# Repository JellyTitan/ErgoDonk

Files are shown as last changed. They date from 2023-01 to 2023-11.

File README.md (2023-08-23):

# ErgoDonk v0.9
ErgoDox variant that uses standard 100% SA keycaps, Blackpill MCU and an FDM printed case. 
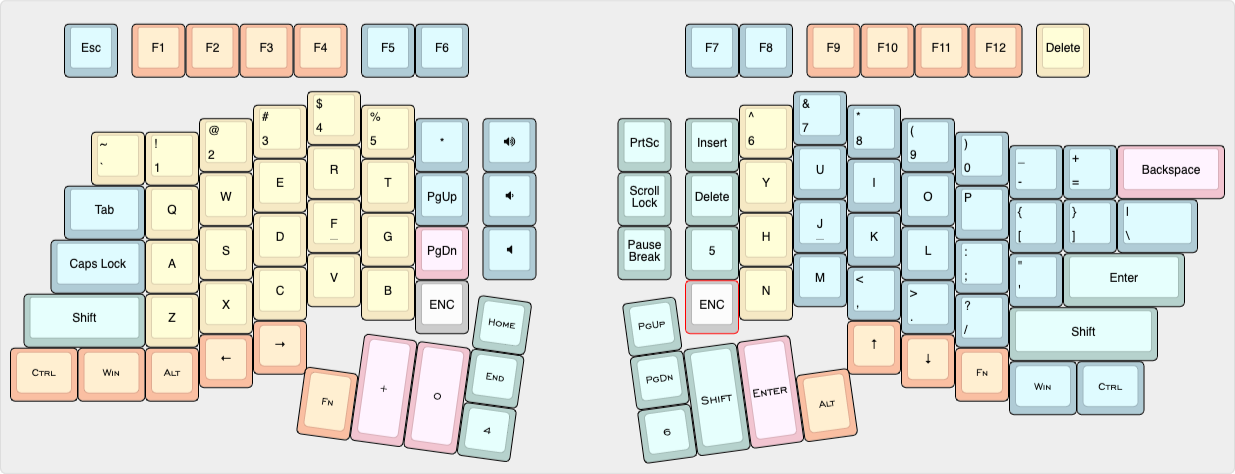
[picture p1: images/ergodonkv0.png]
ErgoDonk key layout

[keyboard layout editor](http://www.keyboard-layout-editor.com/#/gists/ac776db3b0deef94de51943c384cfdfc)

## Build Log
Experiments to date:
* Prototype initially built with Blackpill MCU. Works well.
* Refactored to use LED
* Refactored to use ProMicro
* Refactored to use Pico 2040
* Prototype sent out for production 7-26-2023

### Lessons learned from the ds simple prototype (todo)
* Fix the stabilizers. Two screw-in PCB stabalizers won't fit next to each other on the thumb cluster - try the plate mount stabs instead.
Plate mount stabs mirrored
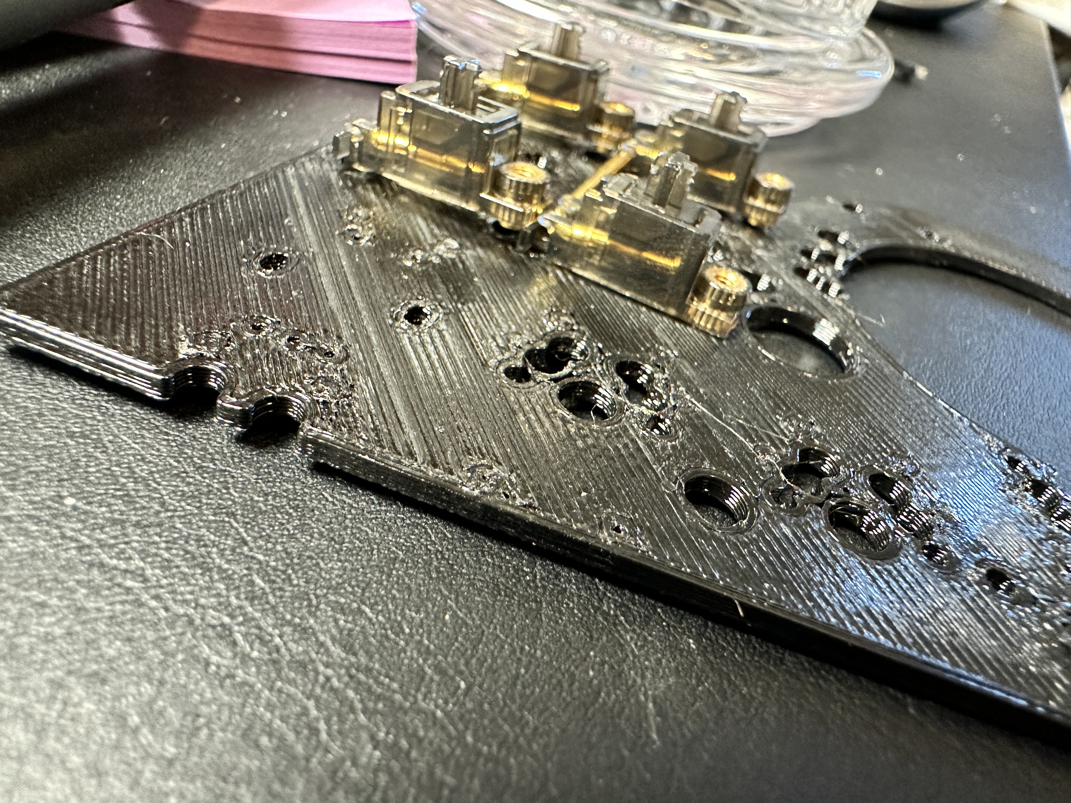
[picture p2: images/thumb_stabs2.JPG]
Plate mount stabs oriented same

* Take a closer look at routing by the rotary encoders - may be a short
* The DS version is charged as two keyboards by JLCPCB - compare pricing for building as two seperate halves.
* The RH Trackball has 2 separate pcbs. Top one sent out for prototype, bottom needs to be made.

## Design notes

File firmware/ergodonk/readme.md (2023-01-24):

# ergodonk_v2

ergodonk_v2

*A short description of the keyboard/project*

* Keyboard Maintainer: [Ryan Neff](https://github.com/JellyTitan)
* Hardware Supported: *The PCBs, controllers supported*
* Hardware Availability: *Links to where you can find this hardware*

Make example for this keyboard (after setting up your build environment):

    make ergodonk_v2:default

Flashing example for this keyboard:

    make ergodonk:default:flash
    For EE_HANDS (Extra steps required on ARM @todo maybe pull this?)
    make ergodonk:default:flash:dfu-util-split-left
    make ergodonk:default:flash:dfu-util-split-right

    qmk compile -kb ergodonk_v2 -km default

    c2json (Must run from inside keymap folder)
    `qmk c2json -kb ergodonk -km default keymap.c`
    
See the [build environment setup](https://docs.qmk.fm/#/getting_started_build_tools) and the [make instructions](https://docs.qmk.fm/#/getting_started_make_guide) for more information. Brand new to QMK? Start with our [Complete Newbs Guide](https://docs.qmk.fm/#/newbs).

## Bootloader

Enter the bootloader in 3 ways:

* **Bootmagic reset**: Hold down the key at (0,0) in the matrix (usually the top left key or Escape) and plug in the keyboard
* **Physical reset button**: Briefly press the button on the back of the PCB - some may have pads you must short instead
* **Keycode in layout**: Press the key mapped to `RESET` if it is available

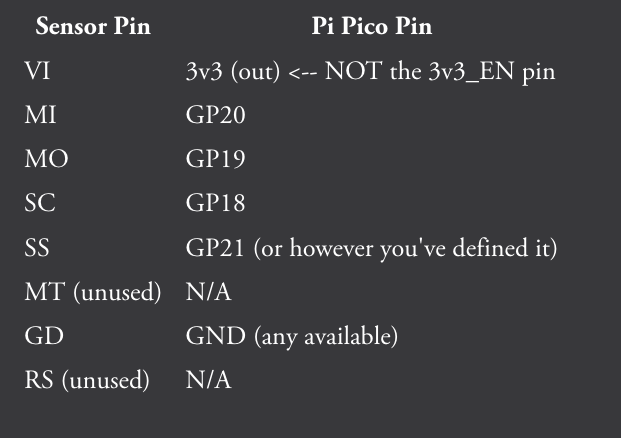
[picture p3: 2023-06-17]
reference_images/pmw3360_pico_pinout.png

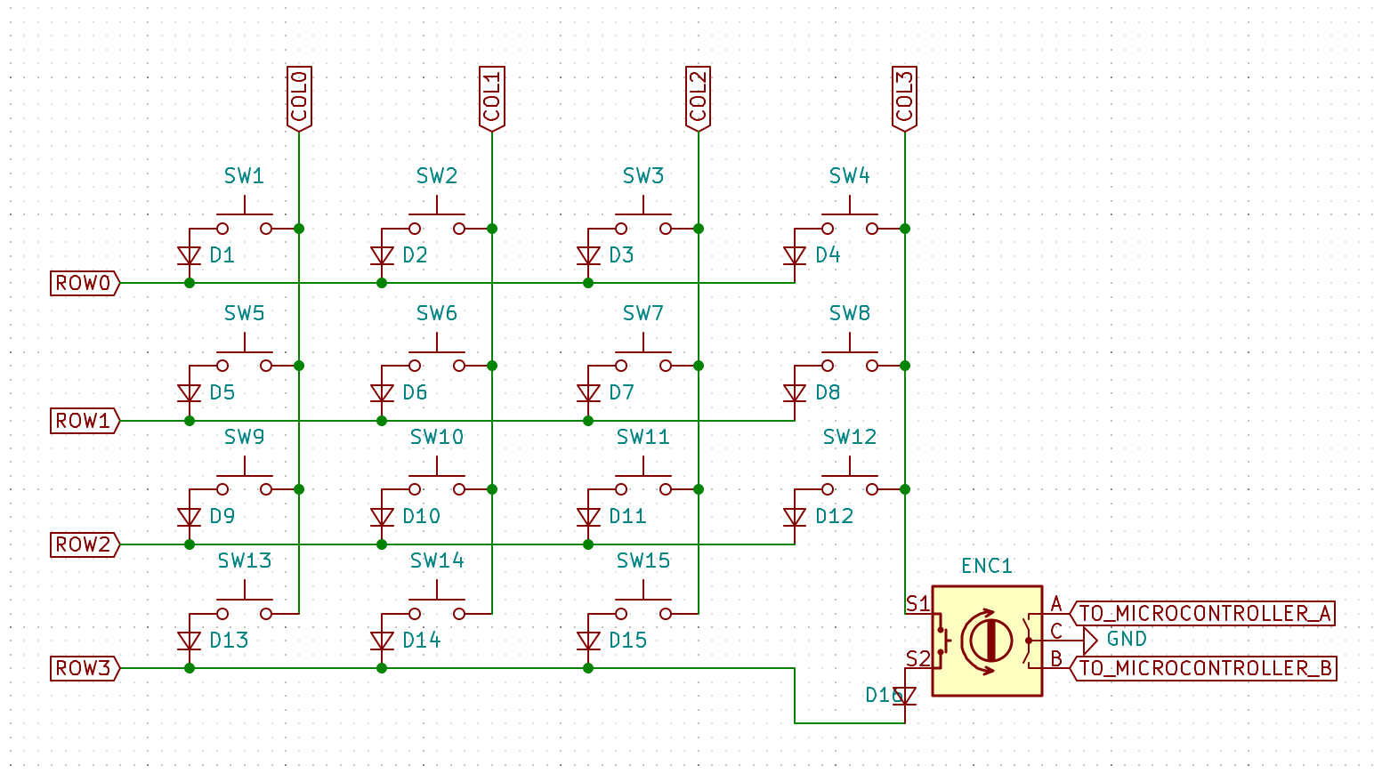
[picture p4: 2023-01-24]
reference_images/rotary_encoder_schematic.png

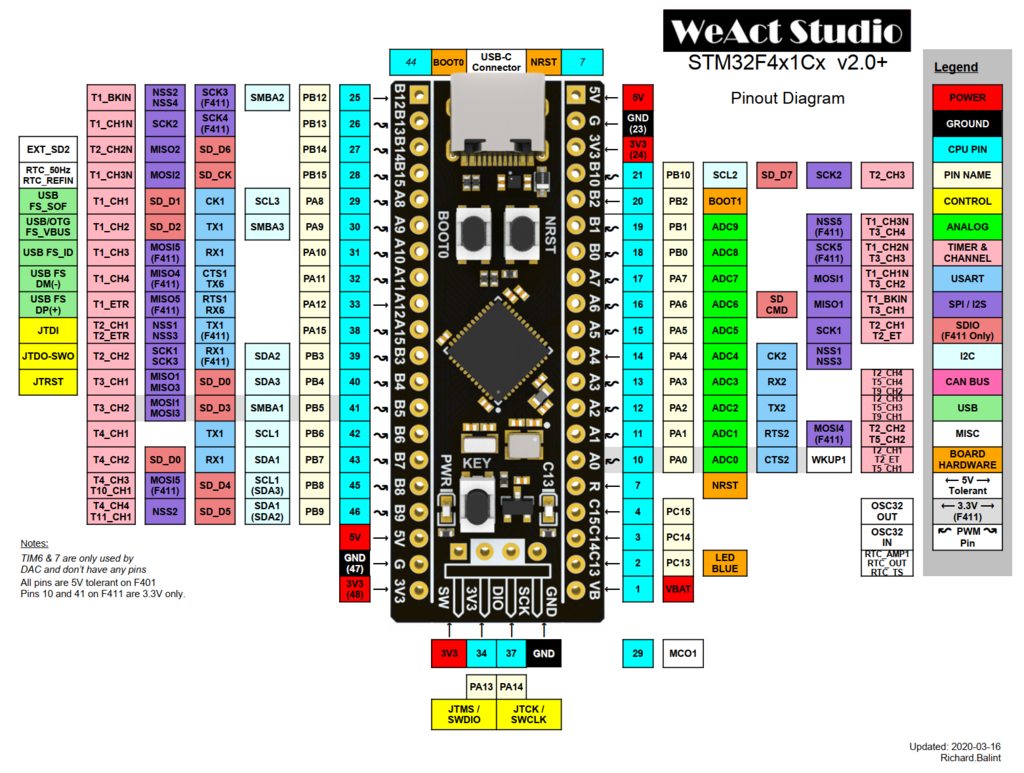
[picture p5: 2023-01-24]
reference_images/blackpill_pinout.jpeg

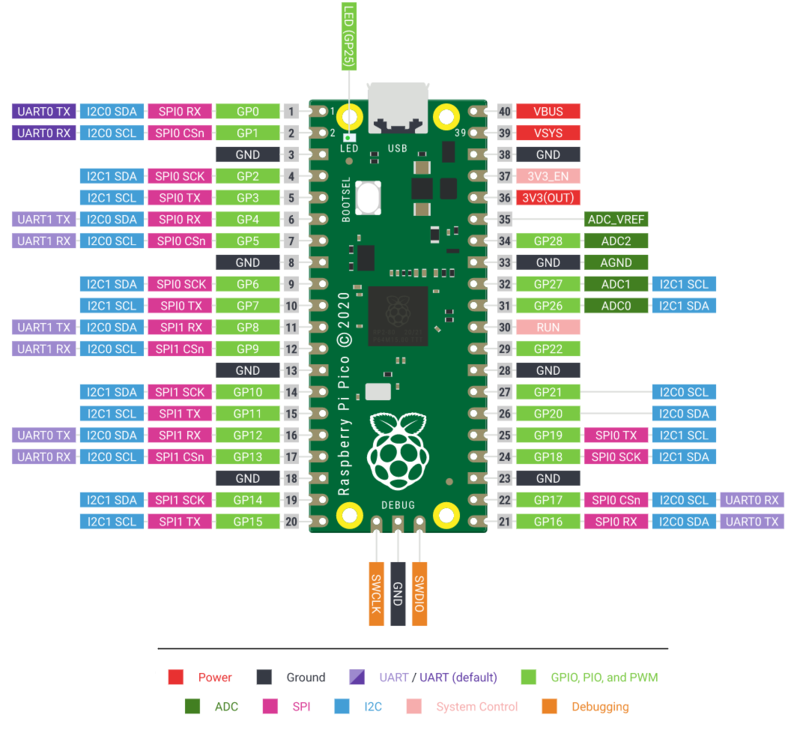
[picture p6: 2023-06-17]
reference_images/raspberry_pi_Pico-R3-Pinout-narrow.png

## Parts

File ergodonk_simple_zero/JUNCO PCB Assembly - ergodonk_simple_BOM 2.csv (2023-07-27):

Comment | Designator | Footprint | JLCPCB Part #（optional）
D | D58,D17,D55,D46,D40,D15,D54,D56,D5,D13,D32,D26,D7,D2,D21,D18,D37,D42,D33,D11,D27,D12,D25,D34,D4,D50,D51,D0,D1,D47,D6,D24,D3,D16,D35,D43,D45,D22,D48_RH10,D20,D38_RH10,D14,D31,D44,D52,D36,D41,D28_RH10,D23,D18_RH10,D08_RH10,D30,D10,D57,D53 | D_SOD-123_DO-35_Hybrid_DoubleSided | C2972760

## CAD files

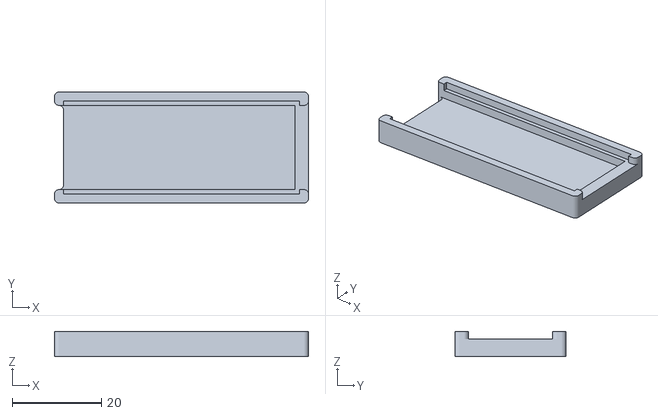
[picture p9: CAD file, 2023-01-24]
blackpill_holder/case.stl
57.0 x 24.9 x 5.71

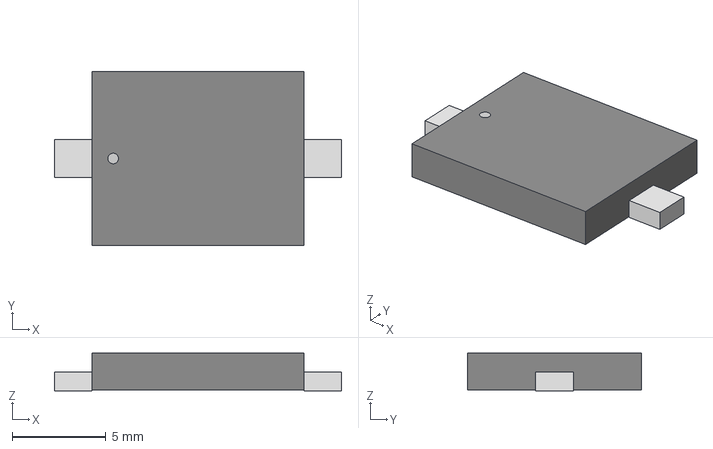
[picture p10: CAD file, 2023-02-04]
ergodonk_kicad_library/3dmodels/AST1109MLTRQ_MAL.step
15.3 x 9.30 x 2.01 mm

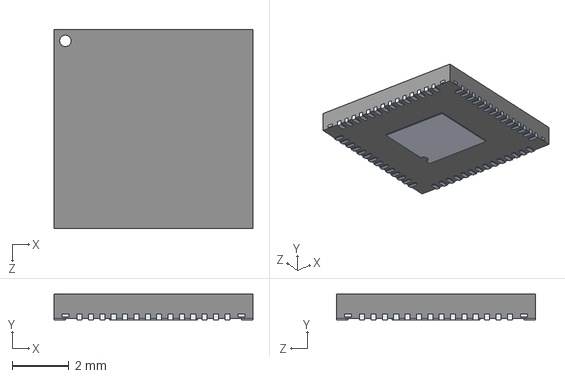
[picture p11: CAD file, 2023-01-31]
ergodonk_kicad_library/RP2040/RP2040.step
7.00 x 0.9 x 7.00 mm

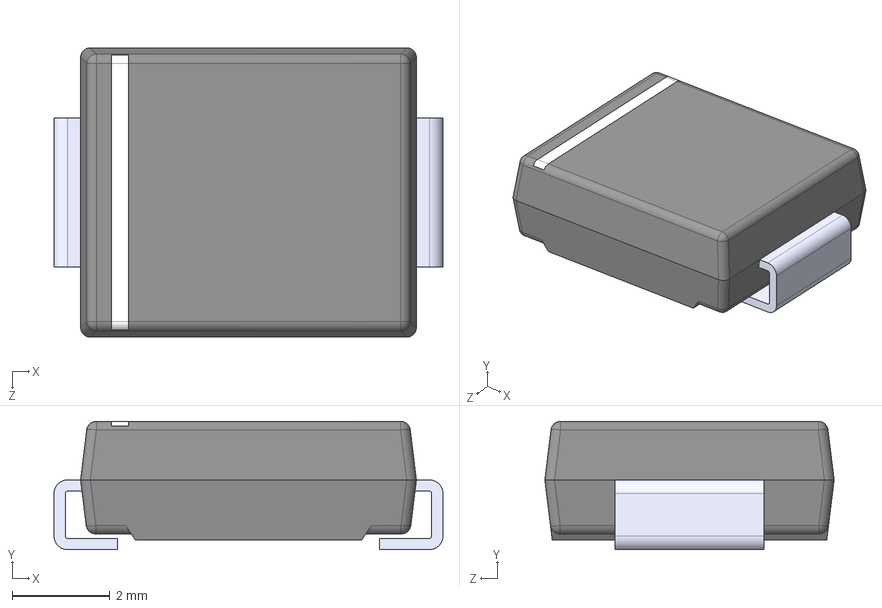
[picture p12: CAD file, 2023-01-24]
ergodonk_simple_zero/ergodonk_simple_0/MUR340S/MUR340S.step
7.94 x 2.62 x 5.90 mm

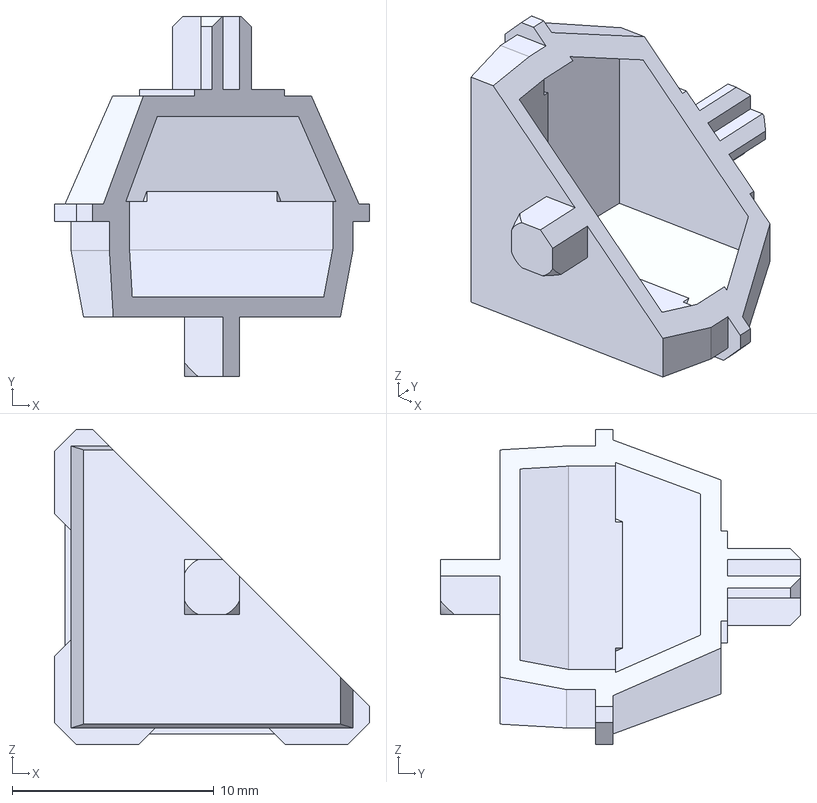
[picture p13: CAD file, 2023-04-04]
reference_images/cherry mx placeholder diagonal v11.step
15.6 x 17.9 x 15.6 mm

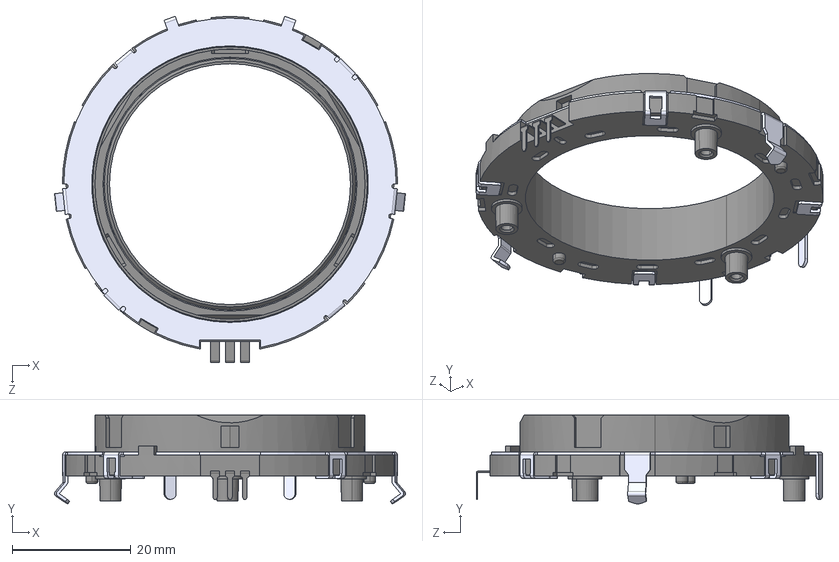
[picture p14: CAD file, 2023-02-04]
ergodonk_kicad_library/3dmodels/PER561-P115-N0015.stp
59.2 x 15.0 x 58.4 mm

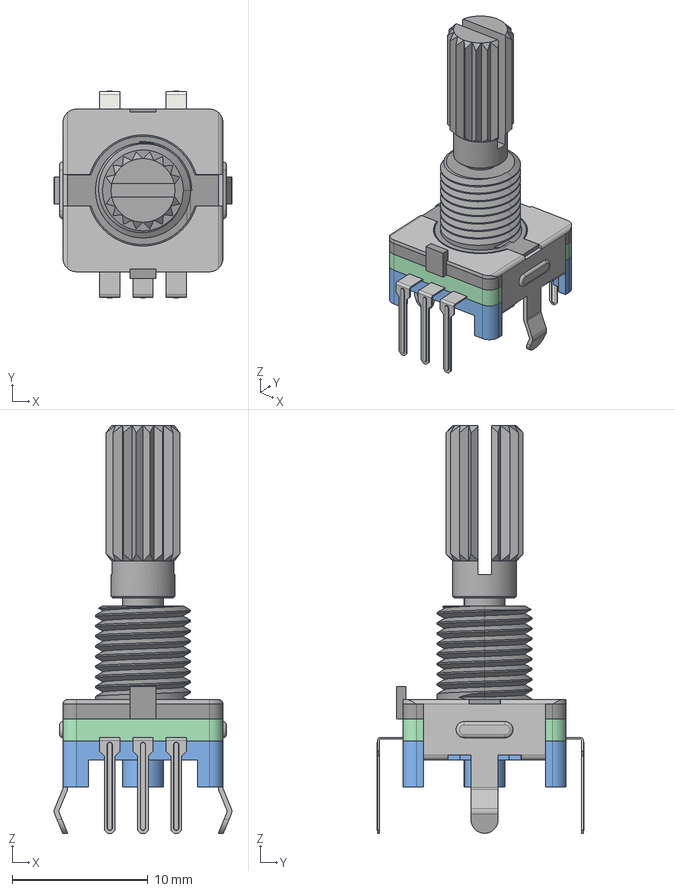
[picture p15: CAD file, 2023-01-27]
ergodonk_kicad_library/3dmodels/EC11_Rotary_Encoder_Switched.step
13.1 x 15.3 x 30.1 mm

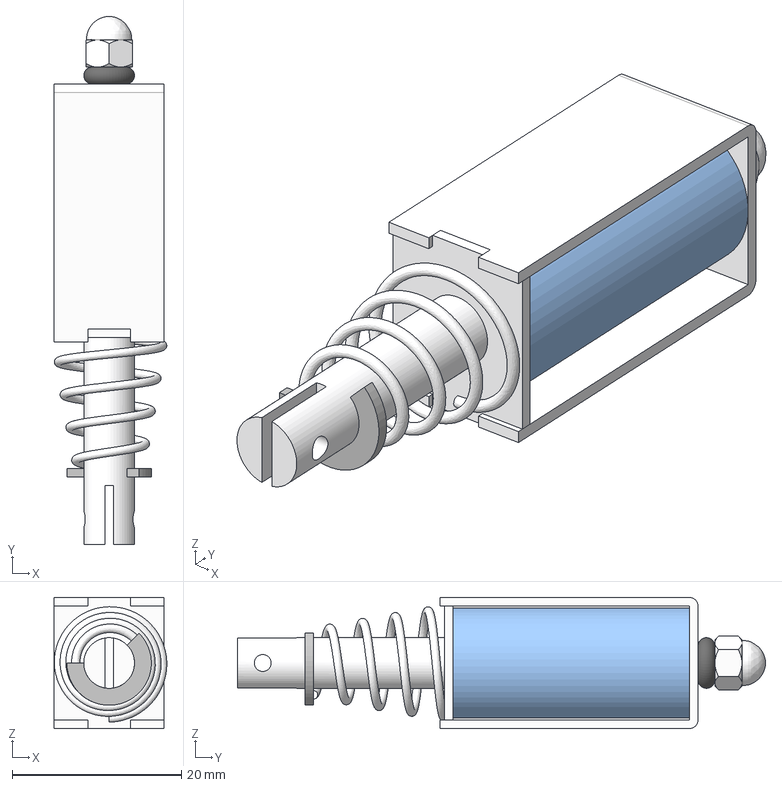
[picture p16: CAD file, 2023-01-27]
ergodonk_kicad_library/3dmodels/solenoid 6V 12V 24V.step
13.3 x 62.5 x 15.5 mm
94000A330_18-8 Stainless Steel Cap Nut

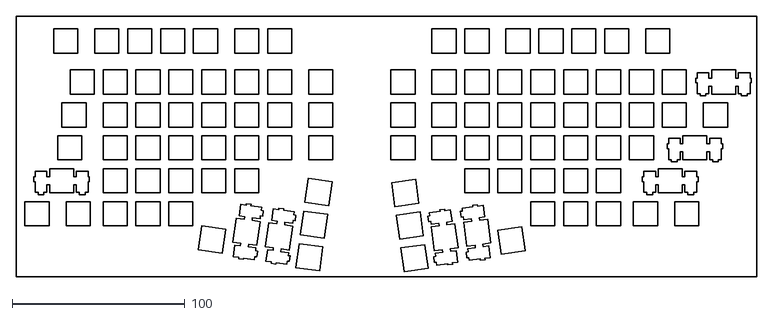
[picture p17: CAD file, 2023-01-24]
builder_swillkb_com/b320815e066426369c427fb329034ee4cbdca748_switch.dxf
428.6 x 150.8

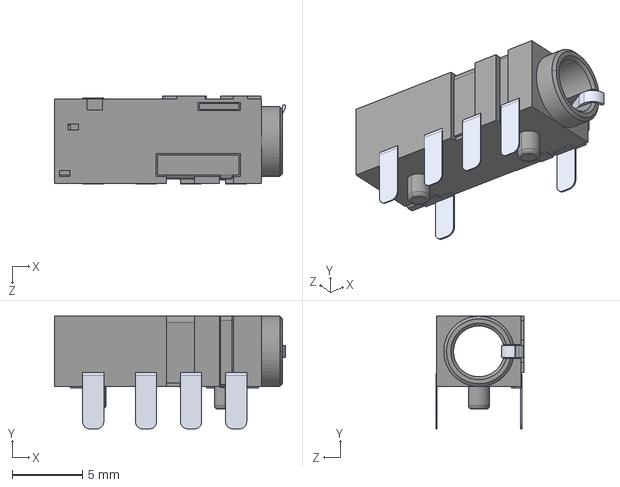
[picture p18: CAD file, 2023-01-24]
ergodonk_kicad_library/3dmodels/FC68128.STEP
16.4 x 8.00 x 6.25 mm

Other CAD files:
ergodonk_kicad_library/3dmodels/FC68128.IGS
ergodonk_kicad_library/3dmodels/FC68128.SLDPRT
ergodonk_kicad_library/3dmodels/FC68128.STL
ergodonk_kicad_library/3dmodels/FC68128.x_t
ergodonk_kicad_library/promicro-arduino-1.snapshot.2/UG-Model/Da-ProMicro.prt
ergodonk_kicad_library/promicro-arduino-1.snapshot.2/UG-Model/Dp-PCB板.prt
ergodonk_kicad_library/promicro-arduino-1.snapshot.2/UG-Model/Dp-Type-C16p.prt
ergodonk_kicad_library/promicro-arduino-1.snapshot.2/UG-Model/Dp-板上元件.prt
ergodonk_kicad_library/promicro-arduino-1.snapshot.2/UG-Model/MICRO_603 cap on pad50205.prt
ergodonk_kicad_library/promicro-arduino-1.snapshot.2/UG-Model/MICRO_603 resistor 1023156.prt
ergodonk_kicad_library/promicro-arduino-1.snapshot.2/UG-Model/MICRO_603 resistor 10356526.prt
ergodonk_kicad_library/promicro-arduino-1.snapshot.2/UG-Model/MICRO_603 resistor 2279914.prt
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

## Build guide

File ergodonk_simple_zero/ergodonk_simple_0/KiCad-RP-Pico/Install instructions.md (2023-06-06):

# Install instructions

## 1. Copy the files locally

Copy the `RP-Pico Libraries` folder wherever you like on your computer.

## 2. Install the Raspberry Pi Pico board schema symbol

Use the `KiCad | Preferences | Manage Symbol Libraries...` command to manage the symbol library:



then select the global tab and click on the folder button:



navigate to the `RP-Pico Libraries` folder, select the `MCU_RaspberryPi_and_Boards.kicad_sym` file and open it:



et voilà, the first step is completed:



You can now close the symbol libraries manager window.

## 3. Install the Raspberry Pi Pico board footprint

You can use a similar approach to add the footprint to the footprint libraries manager, but I've found some issues that I've solved using the footprint editor, so here are the steps I suggest you to follow:

Open the footprint editor



wait for the footprints to load... then use the `File | Add Library` command:



confirm the `Global` choice:



and select the `MCU_RaspberriPi_and_Boards.pretty` folder (yes, the folder represent a footprint library on KiCad):



Now the library is installed on KiCad with the Raspberry Pi Pico footprint (double click on it to see it on the editor pane):



Don't close the windows as the next step start from here.

## 4. Install the Raspberry Pi Pico board footprint 3D visual

If not already open, open the the footprint editor

symbol library manager

double click on the `RPi_Pico_SMD_TH` footprint from the `MCU_RaspberriPi_and_Boards` library and then click on the `Footprint properties` icon:



In the footprint properties window, first select the `3D Settings` tab. Please note that the preview shows only the PCB board with the footprint added on step 3, without any 3D representation of the Raspberry Pi Pico board. Now click on the folder icon to add the 3D model:



Navigate to the `RP-Pico Libraries` folder, select the `Pico.wrl` file and wait until the model is shown in the right panel, then confirm with OK:



The model is already scaled and translated to match the footprint:



now close the `Footprint Properties` window, and the `Footprint Editor`, obviously saving the changes.

## Conclusion

Now that you've installed the schema and footprint and added the 3D model to the footprint, you can use the Raspberry Pi Pico board on your KiCad projects.

I've also added a test KiCad Project on the `Test` folder, that you can use to see an example of it.

Have fun!

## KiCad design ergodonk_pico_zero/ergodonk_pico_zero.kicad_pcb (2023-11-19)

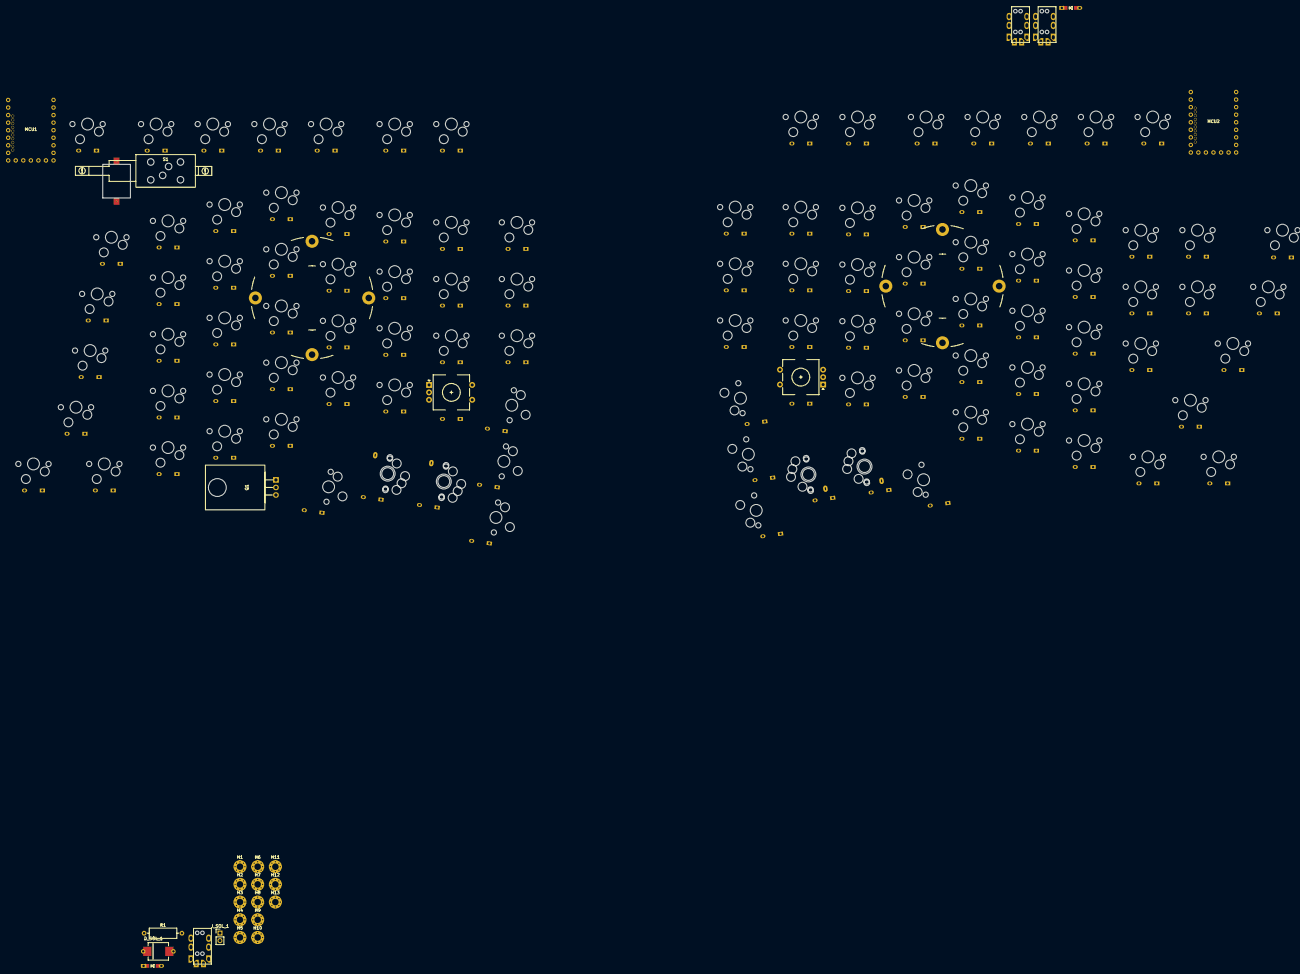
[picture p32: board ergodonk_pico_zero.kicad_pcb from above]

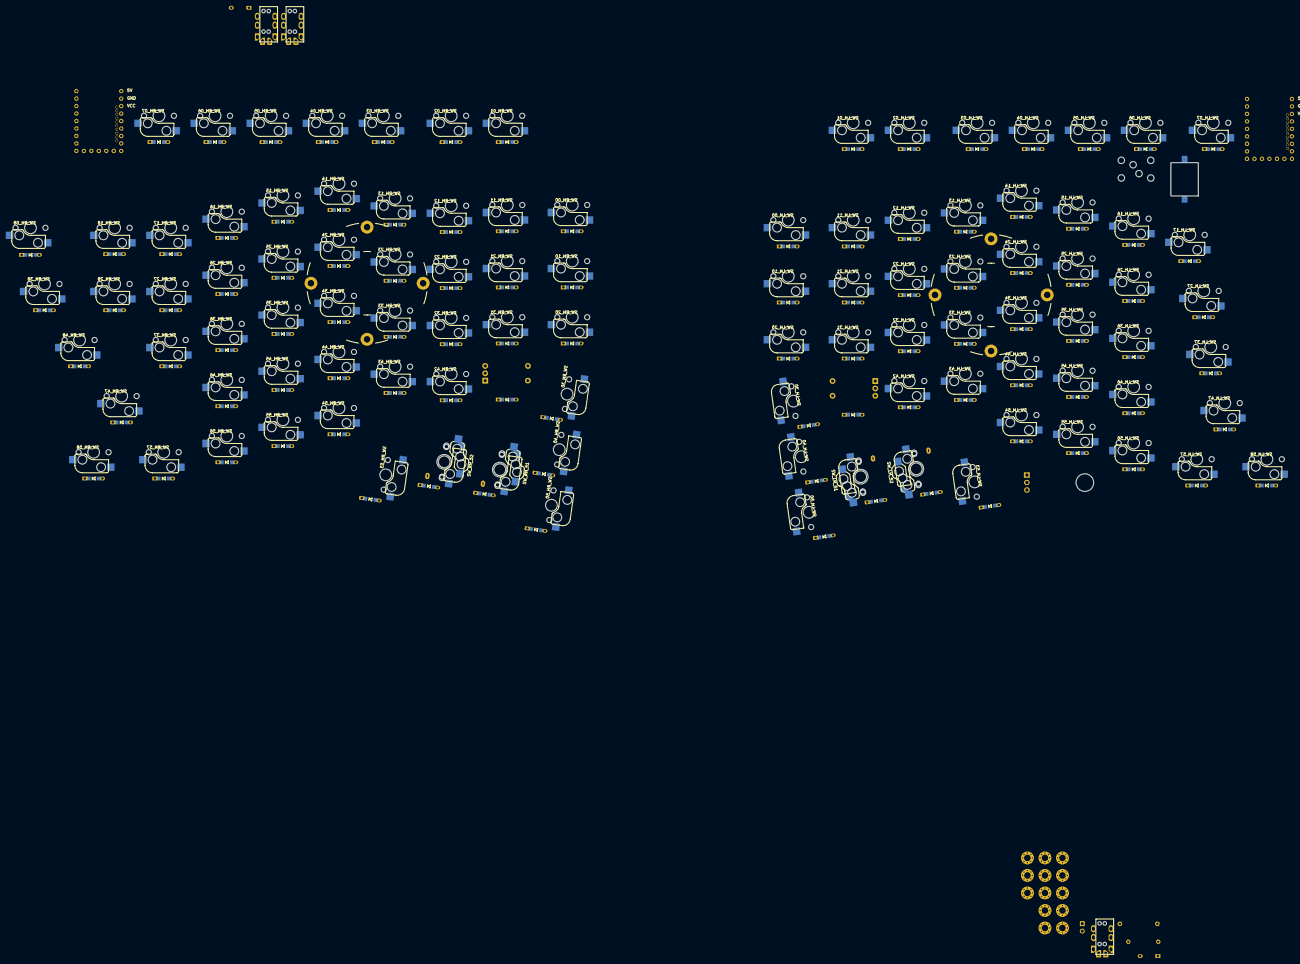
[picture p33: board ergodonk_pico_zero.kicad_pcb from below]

Board: 2 copper layers, 234 parts (204 on the bottom side), 143 nets, no tracks yet.

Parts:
D1, D102: D; D3_TH_SMD_v2
D_LH_00, D_LH_01, D_LH_02, D_LH_03, D_LH_04, D_LH_05, D_LH_06, D_LH_07, D_LH_10, D_LH_11, D_LH_12, D_LH_13, D_LH_14, D_LH_15, D_LH_16, D_LH_17, D_LH_20, D_LH_21, D_LH_22, D_LH_23, D_LH_24, D_LH_25, D_LH_26, D_LH_27, D_LH_30, D_LH_31, D_LH_32, D_LH_33, D_LH_34, D_LH_35, D_LH_36, D_LH_37, D_LH_40, D_LH_41, D_LH_42, D_LH_43, D_LH_44, D_LH_45, D_LH_46, D_LH_47, D_LH_50, D_LH_51, D_LH_52, D_LH_53, D_LH_54, D_LH_55, D_LH_56, D_LH_57, D_LH_58: D; D3_TH_SMD_v2
D_RH_00, D_RH_01, D_RH_02, D_RH_03, D_RH_04, D_RH_05, D_RH_06, D_RH_07, D_RH_08, D_RH_10, D_RH_11, D_RH_12, D_RH_13, D_RH_14, D_RH_15, D_RH_16, D_RH_17, D_RH_18, D_RH_20, D_RH_21, D_RH_22, D_RH_23, D_RH_24, D_RH_25, D_RH_26, D_RH_27, D_RH_28, D_RH_30, D_RH_31, D_RH_32, D_RH_33, D_RH_34, D_RH_35, D_RH_36, D_RH_37, D_RH_38, D_RH_40, D_RH_41, D_RH_42, D_RH_43, D_RH_44, D_RH_45, D_RH_46, D_RH_47, D_RH_48, D_RH_50, D_RH_51, D_RH_52, D_RH_53, D_RH_54, D_RH_55, D_RH_56, D_RH_57, D_RH_58: D; D3_TH_SMD_v2
D_SOL_1: MUR340S; MUR340S_IN4001_TH_HYBRID
H1, H2, H3, H4, H5, H6, H7, H8, H9, H10, H11, H12, H13: MountingHole; MountingHole_2.2mm_M2_Pad_Via
H14, H15: Tenting puck mount; Tenting_Puck.kicad_mod_nocenter
J1, J3, J4: AudioJack4; MJ-4PP-9_CANTOR_KITCHEN_SINK
J_SOL_1: Conn_01x02_Female; PinHeader_1x02_P2.54mm_Vertical
LS1: AST1109MLTRQ_MAL; AST1109MLTRQ
MCU1, MCU2: rp2040-zero; rp2040 Zero DS
Q1: TIP120; Tip 120 with heatsink
R1: 1k; R_Axial_DIN0309_L9.0mm_D3.2mm_P12.70mm_Horizontal
S1: Solenoid; uxcell a14092600ux0438 solenoid
SWLH_ROT1: RotaryEncoder_Switch; RotaryEncoder_EC11_ergodonk_variant
SWRH_ROT1: RotaryEncoder_Switch; RotaryEncoder_EC11_ergodonk_variant
SW_LH_00, SW_LH_01, SW_LH_02, SW_LH_03, SW_LH_04, SW_LH_05, SW_LH_06, SW_LH_07, SW_LH_10, SW_LH_11, SW_LH_12, SW_LH_13, SW_LH_14, SW_LH_15, SW_LH_16, SW_LH_17, SW_LH_20, SW_LH_21, SW_LH_22, SW_LH_23, SW_LH_24, SW_LH_25, SW_LH_26, SW_LH_27, SW_LH_30, SW_LH_31, SW_LH_32, SW_LH_33, SW_LH_34, SW_LH_35, SW_LH_36, SW_LH_37, SW_LH_40, SW_LH_42, SW_LH_43, SW_LH_44, SW_LH_45, SW_LH_46, SW_LH_47, SW_LH_50, SW_LH_53, SW_LH_54, SW_LH_55, SW_LH_56, SW_LH_57, SW_LH_58: SW_PUSH; V2_CherryMX_Hotswap
SW_LH_51, SW_LH_52: SW_PUSH; V2_CherryMX_KailhV2_Hotswap
SW_RH_00, SW_RH_01, SW_RH_02, SW_RH_03, SW_RH_04, SW_RH_05, SW_RH_06, SW_RH_07, SW_RH_08, SW_RH_10, SW_RH_11, SW_RH_12, SW_RH_13, SW_RH_14, SW_RH_15, SW_RH_16, SW_RH_17, SW_RH_18, SW_RH_20, SW_RH_21, SW_RH_22, SW_RH_23, SW_RH_24, SW_RH_25, SW_RH_26, SW_RH_27, SW_RH_28, SW_RH_30, SW_RH_31, SW_RH_32, SW_RH_33, SW_RH_34, SW_RH_35, SW_RH_36, SW_RH_37, SW_RH_38, SW_RH_40, SW_RH_42, SW_RH_43, SW_RH_44, SW_RH_45, SW_RH_46, SW_RH_47, SW_RH_48, SW_RH_50, SW_RH_53, SW_RH_54, SW_RH_55, SW_RH_56, SW_RH_57, SW_RH_58: SW_PUSH; V2_CherryMX_Hotswap
SW_RH_51, SW_RH_52: SW_PUSH; V2_CherryMX_KailhV2_Hotswap

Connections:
+5V: MCU1.23 (5V), MCU2.23 (5V)
GND: LS1.2, MCU1.22 (GND), MCU2.22 (GND), Q1.3 (E), SWLH_ROT1.C, SWRH_ROT1.C
unnamed: D_LH_00.2 (A), SW_LH_00.2
unnamed: D_LH_01.2 (A), SW_LH_01.2
unnamed: D_LH_02.2 (A), SW_LH_02.2
unnamed: D_LH_03.2 (A), SW_LH_03.2
unnamed: D_LH_04.2 (A), SW_LH_04.2
unnamed: D_LH_05.2 (A), SW_LH_05.2
unnamed: D_LH_06.2 (A), SW_LH_06.2
unnamed: D_LH_07.2 (A), SW_LH_07.2
unnamed: D_LH_10.2 (A), SW_LH_10.2
unnamed: D_LH_11.2 (A), SW_LH_11.2
unnamed: D_LH_12.2 (A), SW_LH_12.2
unnamed: D_LH_13.2 (A), SW_LH_13.2
unnamed: D_LH_14.2 (A), SW_LH_14.2
unnamed: D_LH_15.2 (A), SW_LH_15.2
unnamed: D_LH_16.2 (A), SW_LH_16.2
unnamed: D_LH_17.2 (A), SW_LH_17.2
unnamed: D_LH_20.2 (A), SW_LH_20.2
unnamed: D_LH_21.2 (A), SW_LH_21.2
unnamed: D_LH_22.2 (A), SW_LH_22.2
unnamed: D_LH_23.2 (A), SW_LH_23.2
unnamed: D_LH_24.2 (A), SW_LH_24.2
unnamed: D_LH_25.2 (A), SW_LH_25.2
unnamed: D_LH_26.2 (A), SW_LH_26.2
unnamed: D_LH_27.2 (A), SW_LH_27.2
unnamed: D_LH_30.2 (A), SW_LH_30.2
unnamed: D_LH_31.2 (A), SW_LH_31.2
unnamed: D_LH_32.2 (A), SW_LH_32.2
unnamed: D_LH_33.2 (A), SW_LH_33.2
unnamed: D_LH_34.2 (A), SW_LH_34.2
unnamed: D_LH_35.2 (A), SW_LH_35.2
unnamed: D_LH_36.2 (A), SW_LH_36.2
unnamed: D_LH_37.2 (A), SW_LH_37.2
unnamed: D_LH_40.2 (A), SW_LH_40.2
unnamed: D_LH_42.2 (A), SW_LH_42.2
unnamed: D_LH_43.2 (A), SW_LH_43.2
unnamed: D_LH_44.2 (A), SW_LH_44.2
unnamed: D_LH_45.2 (A), SW_LH_45.2
unnamed: D_LH_46.2 (A), SW_LH_46.2
unnamed: D_LH_47.2 (A), SW_LH_47.2
unnamed: D_LH_50.2 (A), SW_LH_50.2
unnamed: D_LH_51.2 (A), SW_LH_51.2
unnamed: D_LH_52.2 (A), SW_LH_52.2
unnamed: D_LH_53.2 (A), SW_LH_53.2
unnamed: D_LH_54.2 (A), SW_LH_54.2
unnamed: D_LH_55.2 (A), SW_LH_55.2
unnamed: D_LH_56.2 (A), SW_LH_56.2
unnamed: D_LH_57.2 (A), SW_LH_57.2
unnamed: D_LH_58.2 (A), SW_LH_58.2
unnamed: D_RH_00.2 (A), SW_RH_00.2
unnamed: D_RH_01.2 (A), SW_RH_01.2
unnamed: D_RH_02.2 (A), SW_RH_02.2
unnamed: D_RH_03.2 (A), SW_RH_03.2
unnamed: D_RH_04.2 (A), SW_RH_04.2
unnamed: D_RH_05.2 (A), SW_RH_05.2
unnamed: D_RH_06.2 (A), SW_RH_06.2
unnamed: D_RH_07.2 (A), SW_RH_07.2
unnamed: D_RH_08.2 (A), SW_RH_08.2
unnamed: D_RH_10.2 (A), SW_RH_10.2
unnamed: D_RH_11.2 (A), SW_RH_11.2
unnamed: D_RH_12.2 (A), SW_RH_12.2
unnamed: D_RH_13.2 (A), SW_RH_13.2
unnamed: D_RH_14.2 (A), SW_RH_14.2
unnamed: D_RH_15.2 (A), SW_RH_15.2
unnamed: D_RH_16.2 (A), SW_RH_16.2
unnamed: D_RH_17.2 (A), SW_RH_17.2
unnamed: D_RH_18.2 (A), SW_RH_18.2
unnamed: D_RH_20.2 (A), SW_RH_20.2
unnamed: D_RH_21.2 (A), SW_RH_21.2
unnamed: D_RH_22.2 (A), SW_RH_22.2
unnamed: D_RH_23.2 (A), SW_RH_23.2
unnamed: D_RH_24.2 (A), SW_RH_24.2
unnamed: D_RH_25.2 (A), SW_RH_25.2
unnamed: D_RH_26.2 (A), SW_RH_26.2
unnamed: D_RH_27.2 (A), SW_RH_27.2
unnamed: D_RH_28.2 (A), SW_RH_28.2
unnamed: D_RH_30.2 (A), SW_RH_30.2
unnamed: D_RH_31.2 (A), SW_RH_31.2
unnamed: D_RH_32.2 (A), SW_RH_32.2
unnamed: D_RH_33.2 (A), SW_RH_33.2
unnamed: D_RH_34.2 (A), SW_RH_34.2
unnamed: D_RH_35.2 (A), SW_RH_35.2
unnamed: D_RH_36.2 (A), SW_RH_36.2
unnamed: D_RH_37.2 (A), SW_RH_37.2
unnamed: D_RH_38.2 (A), SW_RH_38.2
unnamed: D_RH_40.2 (A), SW_RH_40.2
unnamed: D_RH_42.2 (A), SW_RH_42.2
unnamed: D_RH_43.2 (A), SW_RH_43.2
unnamed: D_RH_44.2 (A), SW_RH_44.2
unnamed: D_RH_45.2 (A), SW_RH_45.2
unnamed: D_RH_46.2 (A), SW_RH_46.2
unnamed: D_RH_47.2 (A), SW_RH_47.2
unnamed: D_RH_48.2 (A), SW_RH_48.2
unnamed: D_RH_50.2 (A), SW_RH_50.2
unnamed: D_RH_51.2 (A), SW_RH_51.2
unnamed: D_RH_52.2 (A), SW_RH_52.2
unnamed: D_RH_53.2 (A), SW_RH_53.2
unnamed: D_RH_54.2 (A), SW_RH_54.2
unnamed: D_RH_55.2 (A), SW_RH_55.2
unnamed: D_RH_56.2 (A), SW_RH_56.2
unnamed: D_RH_57.2 (A), SW_RH_57.2
unnamed: D_RH_58.2 (A), SW_RH_58.2
unnamed: D_SOL_1.A, J_SOL_1.1, Q1.2 (C)
unnamed: Q1.1 (B), R1.1
SOLENOID_CONTROL: MCU1.20 (29), R1.2
SW_LH_41_A: MCU1.4 (3), SWLH_ROT1.S1, SW_LH_01.1, SW_LH_11.1, SW_LH_21.1, SW_LH_31.1, SW_LH_51.1
SW_LH_41_B: D_LH_41.2 (A), SWLH_ROT1.S2
SW_RH_41_A: MCU2.4 (3), SWRH_ROT1.S1, SW_RH_01.1, SW_RH_11.1, SW_RH_21.1, SW_RH_31.1, SW_RH_51.1
SW_RH_41_B: D_RH_41.2 (A), SWRH_ROT1.S2
VCC: D1.1 (K), D102.1 (K), D_SOL_1.C, J_SOL_1.2, MCU1.21 (3V3), MCU2.21 (3V3)
col0: MCU1.3 (2), SW_LH_00.1, SW_LH_10.1, SW_LH_20.1, SW_LH_30.1, SW_LH_40.1, SW_LH_50.1
col0_rh: MCU2.3 (2), SW_RH_00.1, SW_RH_10.1, SW_RH_20.1, SW_RH_30.1, SW_RH_40.1, SW_RH_50.1
col2: MCU1.5 (4), SW_LH_02.1, SW_LH_12.1, SW_LH_22.1, SW_LH_32.1, SW_LH_42.1, SW_LH_52.1
col2_rh: MCU2.5 (4), SW_RH_02.1, SW_RH_12.1, SW_RH_22.1, SW_RH_32.1, SW_RH_42.1, SW_RH_52.1
col3: MCU1.6 (5), SW_LH_03.1, SW_LH_13.1, SW_LH_23.1, SW_LH_33.1, SW_LH_43.1, SW_LH_53.1
col3_rh: MCU2.6 (5), SW_RH_03.1, SW_RH_13.1, SW_RH_23.1, SW_RH_33.1, SW_RH_43.1, SW_RH_53.1
col4: MCU1.7 (6), SW_LH_04.1, SW_LH_14.1, SW_LH_24.1, SW_LH_34.1, SW_LH_44.1, SW_LH_54.1
col4_rh: MCU2.7 (6), SW_RH_04.1, SW_RH_14.1, SW_RH_24.1, SW_RH_34.1, SW_RH_44.1, SW_RH_54.1
col5: MCU1.8 (7), SW_LH_05.1, SW_LH_15.1, SW_LH_25.1, SW_LH_35.1, SW_LH_45.1, SW_LH_55.1
col5_rh: MCU2.8 (7), SW_RH_05.1, SW_RH_15.1, SW_RH_25.1, SW_RH_35.1, SW_RH_45.1, SW_RH_55.1
col6: MCU1.9 (8), SW_LH_06.1, SW_LH_16.1, SW_LH_26.1, SW_LH_36.1, SW_LH_46.1, SW_LH_56.1
col6_rh: MCU2.9 (8), SW_RH_06.1, SW_RH_16.1, SW_RH_26.1, SW_RH_36.1, SW_RH_46.1, SW_RH_56.1
col7: MCU1.13 (12), SW_LH_07.1, SW_LH_17.1, SW_LH_27.1, SW_LH_37.1, SW_LH_47.1, SW_LH_57.1
col7_rh: MCU2.13 (12), SW_RH_07.1, SW_RH_17.1, SW_RH_27.1, SW_RH_37.1, SW_RH_47.1, SW_RH_57.1
col8: MCU1.12 (11), SW_LH_58.1
col8_rh: MCU2.12 (11), SW_RH_08.1, SW_RH_18.1, SW_RH_28.1, SW_RH_38.1, SW_RH_48.1, SW_RH_58.1
data1RX: MCU1.2 (1), MCU2.2 (1)
data1TX: MCU1.1 (0), MCU2.1 (0)
encA_rh: MCU2.11 (10), SWRH_ROT1.A
encB_rh: MCU2.10 (9), SWRH_ROT1.B
row0: D_LH_00.1 (K), D_LH_01.1 (K), D_LH_02.1 (K), D_LH_03.1 (K), D_LH_04.1 (K), D_LH_05.1 (K), D_LH_06.1 (K), D_LH_07.1 (K), MCU1.19 (28)
row0_rh: D_RH_00.1 (K), D_RH_01.1 (K), D_RH_02.1 (K), D_RH_03.1 (K), D_RH_04.1 (K), D_RH_05.1 (K), D_RH_06.1 (K), D_RH_07.1 (K), D_RH_08.1 (K), MCU2.19 (28)
row1: D_LH_10.1 (K), D_LH_11.1 (K), D_LH_12.1 (K), D_LH_13.1 (K), D_LH_14.1 (K), D_LH_15.1 (K), D_LH_16.1 (K), D_LH_17.1 (K), MCU1.18 (27)
row1_rh: D_RH_10.1 (K), D_RH_11.1 (K), D_RH_12.1 (K), D_RH_13.1 (K), D_RH_14.1 (K), D_RH_15.1 (K), D_RH_16.1 (K), D_RH_17.1 (K), D_RH_18.1 (K), MCU2.18 (27)
row2: D_LH_20.1 (K), D_LH_21.1 (K), D_LH_22.1 (K), D_LH_23.1 (K), D_LH_24.1 (K), D_LH_25.1 (K), D_LH_26.1 (K), D_LH_27.1 (K), MCU1.17 (26)
row2_rh: D_RH_20.1 (K), D_RH_21.1 (K), D_RH_22.1 (K), D_RH_23.1 (K), D_RH_24.1 (K), D_RH_25.1 (K), D_RH_26.1 (K), D_RH_27.1 (K), D_RH_28.1 (K), MCU2.17 (26)
row3: D_LH_30.1 (K), D_LH_31.1 (K), D_LH_32.1 (K), D_LH_33.1 (K), D_LH_34.1 (K), D_LH_35.1 (K), D_LH_36.1 (K), D_LH_37.1 (K), MCU1.16 (15)
row3_rh: D_RH_30.1 (K), D_RH_31.1 (K), D_RH_32.1 (K), D_RH_33.1 (K), D_RH_34.1 (K), D_RH_35.1 (K), D_RH_36.1 (K), D_RH_37.1 (K), D_RH_38.1 (K), MCU2.16 (15)
row4: D_LH_40.1 (K), D_LH_41.1 (K), D_LH_42.1 (K), D_LH_43.1 (K), D_LH_44.1 (K), D_LH_45.1 (K), D_LH_46.1 (K), D_LH_47.1 (K), MCU1.15 (14)
row4_rh: D_RH_40.1 (K), D_RH_41.1 (K), D_RH_42.1 (K), D_RH_43.1 (K), D_RH_44.1 (K), D_RH_45.1 (K), D_RH_46.1 (K), D_RH_47.1 (K), D_RH_48.1 (K), MCU2.15 (14)
row5: D_LH_50.1 (K), D_LH_51.1 (K), D_LH_52.1 (K), D_LH_53.1 (K), D_LH_54.1 (K), D_LH_55.1 (K), D_LH_56.1 (K), D_LH_57.1 (K), D_LH_58.1 (K), MCU1.14 (13)
row5_rh: D_RH_50.1 (K), D_RH_51.1 (K), D_RH_52.1 (K), D_RH_53.1 (K), D_RH_54.1 (K), D_RH_55.1 (K), D_RH_56.1 (K), D_RH_57.1 (K), D_RH_58.1 (K), MCU2.14 (13)

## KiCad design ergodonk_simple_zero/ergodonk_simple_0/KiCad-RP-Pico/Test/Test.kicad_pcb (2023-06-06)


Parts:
J1, J2: Conn_01x20; PinSocket_1x20_P1.00mm_Vertical
J3: Conn_01x03; PinSocket_1x03_P1.00mm_Vertical
U1: Pico; RPi_Pico_SMD_TH

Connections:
GND: J1.3, J1.8, J1.13, J1.18, J2.3, J2.13, J2.18, J3.2, U1.3 (GND), U1.8 (GND), U1.13 (GND), U1.18 (GND), U1.23 (GND), U1.28 (GND), U1.38 (GND), U1.42 (GND)
unnamed: J1.1, U1.1 (GPIO0)
unnamed: J1.2, U1.2 (GPIO1)
unnamed: J1.4, U1.4 (GPIO2)
unnamed: J1.5, U1.5 (GPIO3)
unnamed: J1.6, U1.6 (GPIO4)
unnamed: J1.7, U1.7 (GPIO5)
unnamed: J1.9, U1.9 (GPIO6)
unnamed: J1.10, U1.10 (GPIO7)
unnamed: J1.11, U1.11 (GPIO8)
unnamed: J1.12, U1.12 (GPIO9)
unnamed: J1.14, U1.14 (GPIO10)
unnamed: J1.15, U1.15 (GPIO11)
unnamed: J1.16, U1.16 (GPIO12)
unnamed: J1.17, U1.17 (GPIO13)
unnamed: J1.19, U1.19 (GPIO14)
unnamed: J1.20, U1.20 (GPIO15)
unnamed: J2.1, U1.40 (VBUS)
unnamed: J2.2, U1.39 (VSYS)
unnamed: J2.4, U1.37 (3V3_EN)
unnamed: J2.5, U1.36 (3V3)
unnamed: J2.6, U1.35 (ADC_VREF)
unnamed: J2.7, U1.34 (GPIO28_ADC2)
unnamed: J2.8, U1.33 (AGND)
unnamed: J2.9, U1.32 (GPIO27_ADC1)
unnamed: J2.10, U1.31 (GPIO26_ADC0)
unnamed: J2.11, U1.30 (RUN)
unnamed: J2.12, U1.29 (GPIO22)
unnamed: J2.14, U1.27 (GPIO21)
unnamed: J2.15, U1.26 (GPIO20)
unnamed: J2.16, U1.25 (GPIO19)
unnamed: J2.17, U1.24 (GPIO18)
unnamed: J2.19, U1.22 (GPIO17)
unnamed: J2.20, U1.21 (GPIO16)
unnamed: J3.1, U1.43 (SWDIO)
unnamed: J3.3, U1.41 (SWCLK)


Board: 2 copper layers, 43.0 x 65.0 mm, 4 parts (0 on the bottom side), 36 nets.

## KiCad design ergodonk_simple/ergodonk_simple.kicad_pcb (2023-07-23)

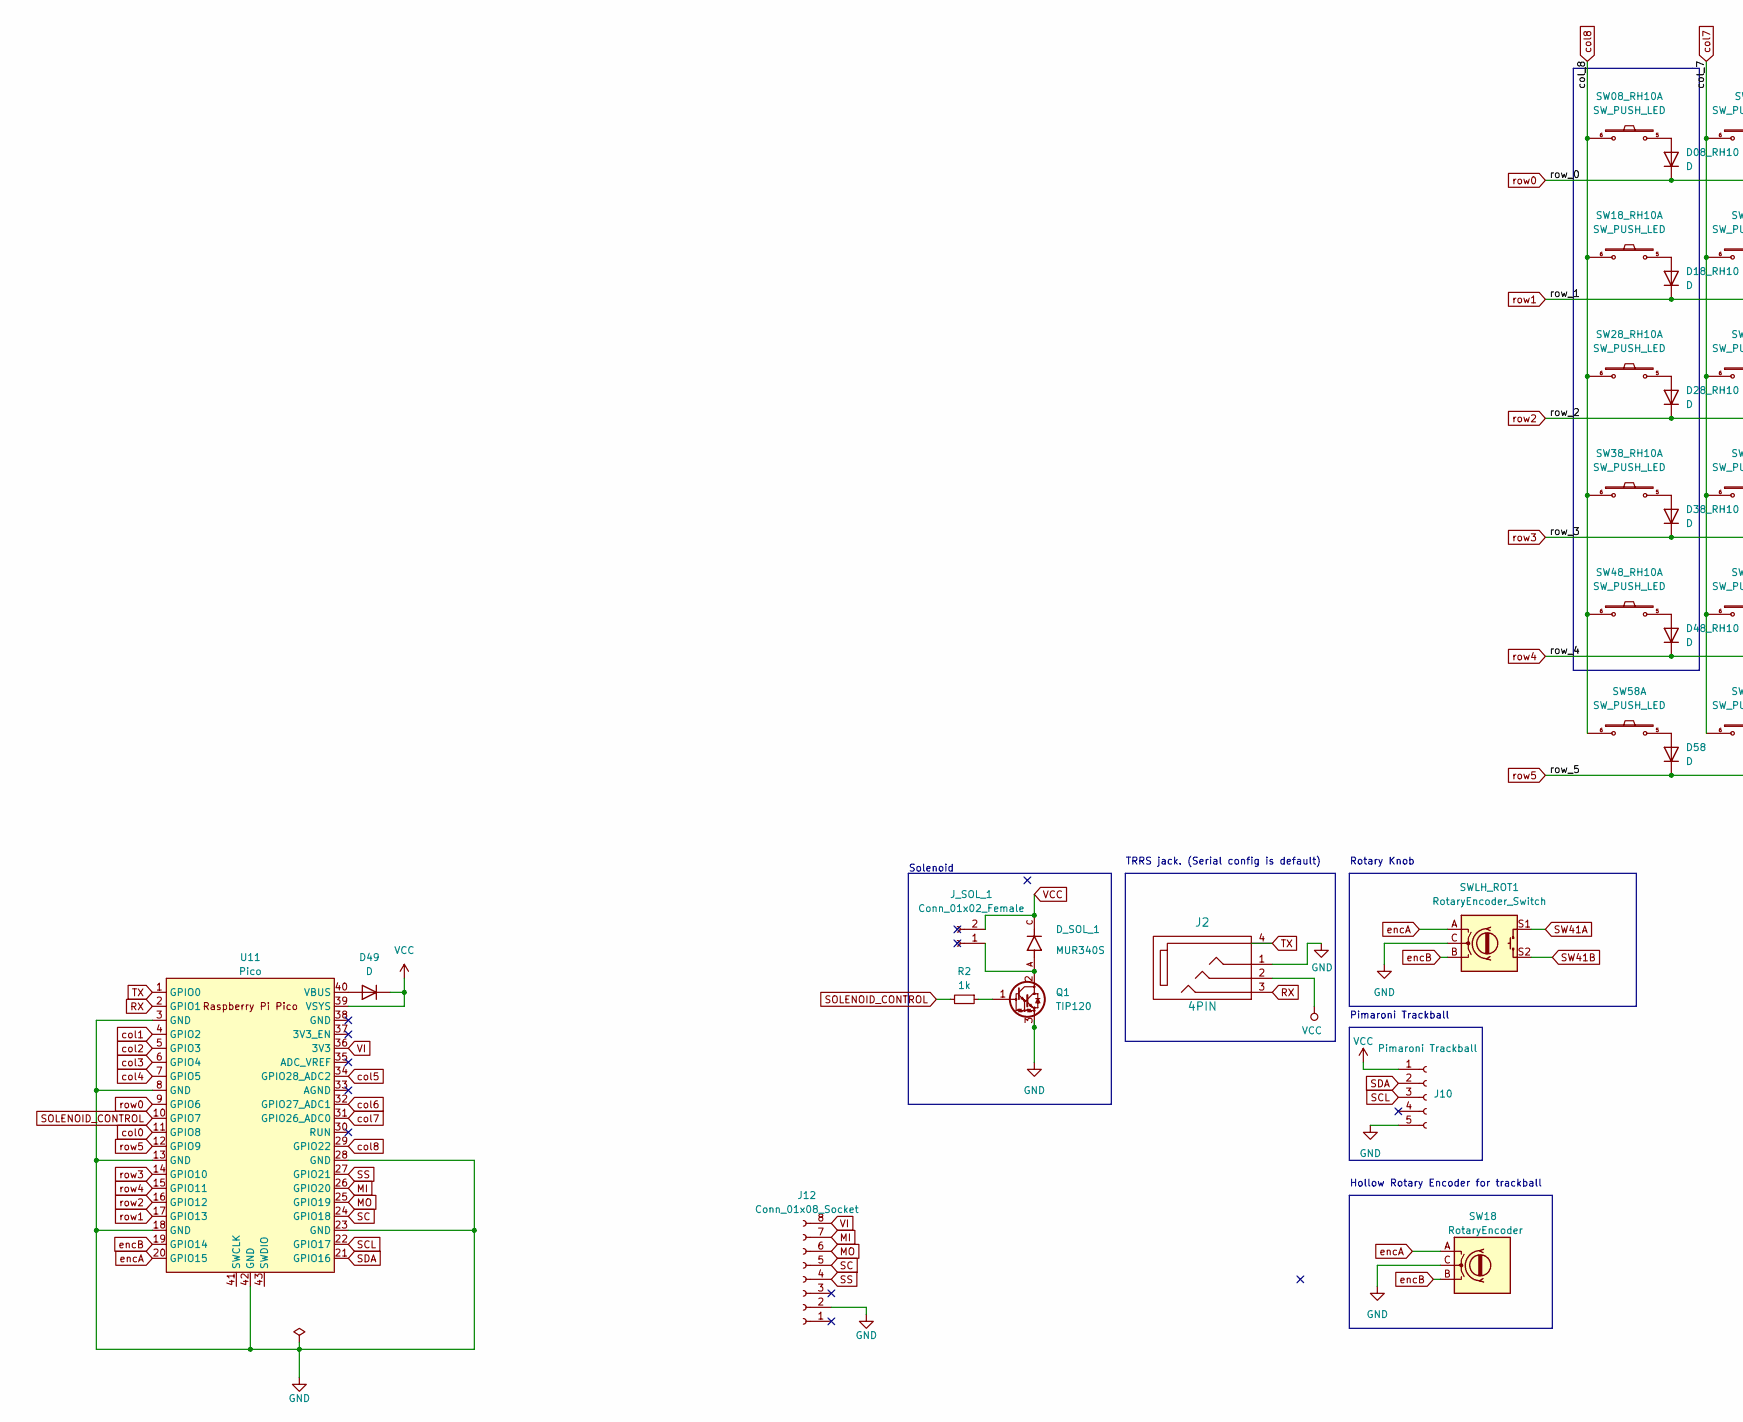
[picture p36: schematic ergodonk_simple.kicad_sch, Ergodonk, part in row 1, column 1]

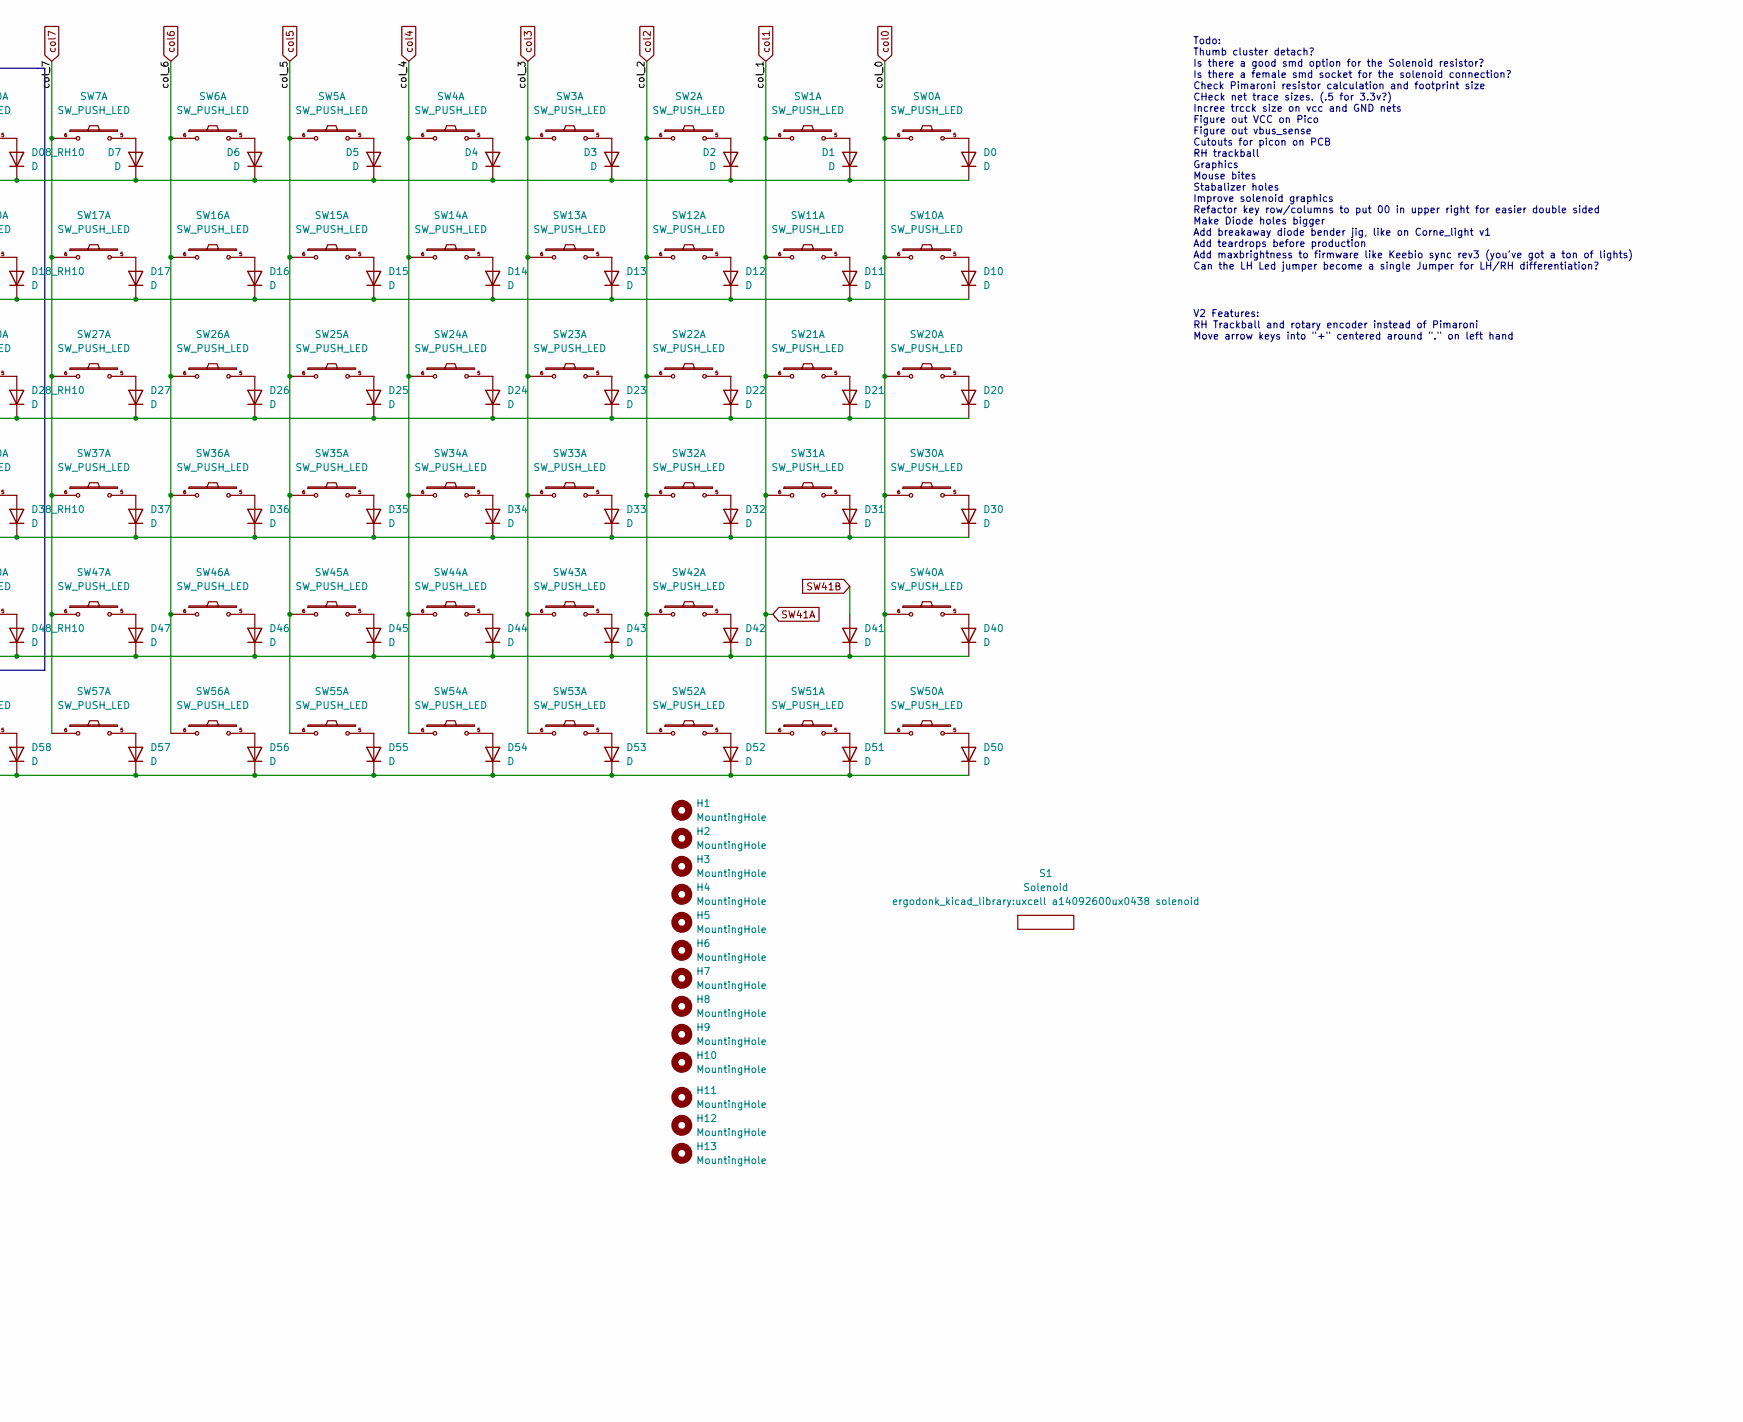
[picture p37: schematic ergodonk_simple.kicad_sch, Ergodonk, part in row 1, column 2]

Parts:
D0, D1, D2, D3, D4, D5, D6, D7, D08_RH10, D10, D11, D12, D13, D14, D15, D16, D17, D18_RH10, D20, D21, D22, D23, D24, D25, D26, D27, D28_RH10, D30, D31, D32, D33, D34, D35, D36, D37, D38_RH10, D40, D41, D42, D43, D44, D45, D46, D47, D48_RH10, D50, D51, D52, D53, D54, D55, D56, D57, D58: D; D_SOD-123_DO-35_Hybrid_DoubleSided
D49: D; D3_TH_SMD_v2
D_SOL_1: MUR340S; MUR340S_IN4001_TH_HYBRID; PARTREV L2102
H1, H2, H3, H4, H5, H6, H7, H8, H9, H10, H11, H12, H13: MountingHole; Hole from sofle for M2 posts gold rimmer
J2: 4PIN; MJ-4PP-9_CANTOR_KITCHEN_SINK
J10: Pimaroni Trackball; pimoroni_trackball_no_cutout
J12: Conn_01x08_Socket; PinHeader_1x08_P2.54mm_Vertical
J_SOL_1: Conn_01x02_Female; PinHeader_1x02_P2.54mm_Vertical
Q1: TIP120; TO-220-3_Horizontal_TabDown
R2: 1k; R_Axial_DIN0309_L9.0mm_D3.2mm_P12.70mm_Horizontal
S1: Solenoid; uxcell a14092600ux0438 solenoid
SW0, SW1, SW2, SW3, SW4, SW5, SW6, SW7, SW10, SW11, SW12, SW13, SW14, SW15, SW16, SW17, SW20, SW21, SW22, SW23, SW24, SW25, SW26, SW30, SW31, SW32, SW33, SW34, SW35, SW36, SW40, SW42, SW43, SW44, SW45, SW46, SW50, SW51, SW52, SW53, SW54, SW55, SW56, SW57, SW58: SW_PUSH_LED; Cherry_MX_DS_Hotswap_1U_sofle3b v3
SW08_RH10: SW_PUSH_LED; V2_CherryMX_DoubleSided_Hotswap_miniE_2u_RH_ONLY
SW18: RotaryEncoder; Bourns Hollow Encoder V1
SW18_RH10, SW38_RH10: SW_PUSH_LED; Cherry_MX_DS_Hotswap_1U_oneside
SW27: SW_PUSH_LED; V2_CherryMX_DoubleSided_Hotswap_miniE_1.5u_LH_1u_RH
SW28_RH10: SW_PUSH_LED; V2_CherryMX_DoubleSided_Hotswap_miniE_1.5u_RH_ONLY
SW37: SW_PUSH_LED; V2_CherryMX_DoubleSided_Hotswap_miniE_1.75u_LH_1u_RH
SW47: SW_PUSH_LED; V2_CherryMX_DoubleSided_Hotswap_miniE_2.25u_LH_2.75u_RH
SW48_RH10: SW_PUSH_LED; V2_CherryMX_DoubleSided_Hotswap_miniE_2.25u_RH_ONLY
SWLH_ROT1: RotaryEncoder_Switch; RotaryEncoder_EC11_ergodonk_variant
U11: Pico; RPi_Pico_SMD_TH_DS_Simple_v1

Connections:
GND: J10.5, J12.2, Q1.3 (E), SW18.C, SWLH_ROT1.C, U11.3 (GND), U11.8 (GND), U11.13 (GND), U11.18 (GND), U11.23 (GND), U11.28 (GND), U11.42 (GND); also elsewhere on the board
MI: J12.7, U11.26 (GPIO20)
MO: J12.6, U11.25 (GPIO19)
unnamed: D0.2 (A), SW0.5
unnamed: D1.2 (A), SW1.5
unnamed: D2.2 (A), SW2.5
unnamed: D3.2 (A), SW3.5
unnamed: D4.2 (A), SW4.5
unnamed: D5.2 (A), SW5.5
unnamed: D6.2 (A), SW6.5
unnamed: D7.2 (A), SW7.5
unnamed: D08_RH10.2 (A), SW08_RH10.5
unnamed: D10.2 (A), SW10.5
unnamed: D11.2 (A), SW11.5
unnamed: D12.2 (A), SW12.5
unnamed: D13.2 (A), SW13.5
unnamed: D14.2 (A), SW14.5
unnamed: D15.2 (A), SW15.5
unnamed: D16.2 (A), SW16.5
unnamed: D17.2 (A), SW17.5
unnamed 20: U11.40 (VBUS); also elsewhere on the board
unnamed: D18_RH10.2 (A), SW18_RH10.5
unnamed: D20.2 (A), SW20.5
unnamed: D21.2 (A), SW21.5
unnamed: D22.2 (A), SW22.5
unnamed: D23.2 (A), SW23.5
unnamed: D24.2 (A), SW24.5
unnamed: D25.2 (A), SW25.5
unnamed: D26.2 (A), SW26.5
unnamed: D27.2 (A), SW27.5
unnamed: D28_RH10.2 (A), SW28_RH10.5
unnamed: D30.2 (A), SW30.5
unnamed: D31.2 (A), SW31.5
unnamed: D32.2 (A), SW32.5
unnamed: D33.2 (A), SW33.5
unnamed: D34.2 (A), SW34.5
unnamed: D35.2 (A), SW35.5
unnamed: D36.2 (A), SW36.5
unnamed: D37.2 (A), SW37.5
unnamed: D38_RH10.2 (A), SW38_RH10.5
unnamed: D40.2 (A), SW40.5
unnamed: D42.2 (A), SW42.5
unnamed: D43.2 (A), SW43.5
unnamed: D44.2 (A), SW44.5
unnamed: D45.2 (A), SW45.5
unnamed: D46.2 (A), SW46.5
unnamed: D47.2 (A), SW47.5
unnamed: D48_RH10.2 (A), SW48_RH10.5
unnamed: D50.2 (A), SW50.5
unnamed: D51.2 (A), SW51.5
unnamed: D52.2 (A), SW52.5
unnamed: D53.2 (A), SW53.5
unnamed: D54.2 (A), SW54.5
unnamed: D55.2 (A), SW55.5
unnamed: D56.2 (A), SW56.5
unnamed: D57.2 (A), SW57.5
unnamed: D58.2 (A), SW58.5
unnamed: D_SOL_1.A, J_SOL_1.1, Q1.2 (C)
unnamed: Q1.1 (B), R2.1
RX: U11.2 (GPIO1); also elsewhere on the board
SC: J12.5, U11.24 (GPIO18)
SCL: J10.3, U11.22 (GPIO17)
SDA: J10.2, U11.21 (GPIO16)
SOLENOID_CONTROL: R2.2, U11.10 (GPIO7)
SS: J12.4, U11.27 (GPIO21)
SW41A: SW1.6, SW11.6, SW21.6, SW31.6, SW51.6, SWLH_ROT1.S1, U11.4 (GPIO2)
SW41B: D41.2 (A), SWLH_ROT1.S2
TX: U11.1 (GPIO0); also elsewhere on the board
VCC: D_SOL_1.C, J10.1, J_SOL_1.2, U11.39 (VSYS); also elsewhere on the board
VI: J12.8, U11.36 (3V3)
col0: SW0.6, SW10.6, SW20.6, SW30.6, SW40.6, SW50.6, U11.11 (GPIO8)
col2: SW2.6, SW12.6, SW22.6, SW32.6, SW42.6, SW52.6, U11.5 (GPIO3)
col3: SW3.6, SW13.6, SW23.6, SW33.6, SW43.6, SW53.6, U11.6 (GPIO4)
col4: SW4.6, SW14.6, SW24.6, SW34.6, SW44.6, SW54.6, U11.7 (GPIO5)
col5: SW5.6, SW15.6, SW25.6, SW35.6, SW45.6, SW55.6, U11.34 (GPIO28_ADC2)
col6: SW6.6, SW16.6, SW26.6, SW36.6, SW46.6, SW56.6, U11.32 (GPIO27_ADC1)
col7: SW7.6, SW17.6, SW27.6, SW37.6, SW47.6, SW57.6, U11.31 (GPIO26_ADC0)
col8: SW08_RH10.6, SW18_RH10.6, SW28_RH10.6, SW38_RH10.6, SW48_RH10.6, SW58.6, U11.29 (GPIO22)
encA: SW18.A, SWLH_ROT1.A, U11.20 (GPIO15)
encB: SW18.B, SWLH_ROT1.B, U11.19 (GPIO14)
row0: D0.1 (K), D1.1 (K), D2.1 (K), D3.1 (K), D4.1 (K), D5.1 (K), D6.1 (K), D7.1 (K), D08_RH10.1 (K), U11.9 (GPIO6)
row1: D10.1 (K), D11.1 (K), D12.1 (K), D13.1 (K), D14.1 (K), D15.1 (K), D16.1 (K), D17.1 (K), D18_RH10.1 (K), U11.17 (GPIO13)
row2: D20.1 (K), D21.1 (K), D22.1 (K), D23.1 (K), D24.1 (K), D25.1 (K), D26.1 (K), D27.1 (K), D28_RH10.1 (K), U11.16 (GPIO12)
row3: D30.1 (K), D31.1 (K), D32.1 (K), D33.1 (K), D34.1 (K), D35.1 (K), D36.1 (K), D37.1 (K), D38_RH10.1 (K), U11.14 (GPIO10)
row4: D40.1 (K), D41.1 (K), D42.1 (K), D43.1 (K), D44.1 (K), D45.1 (K), D46.1 (K), D47.1 (K), D48_RH10.1 (K), U11.15 (GPIO11)
row5: D50.1 (K), D51.1 (K), D52.1 (K), D53.1 (K), D54.1 (K), D55.1 (K), D56.1 (K), D57.1 (K), D58.1 (K), U11.12 (GPIO9)

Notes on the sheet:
Todo: Thumb cluster detach? Is there a good smd option for the Solenoid resistor? Is there a female smd socket for the solenoid connection? Check Pimaroni resistor calculation and footprint size CHeck net trace sizes. (.5 for 3.3v?) Incree trcck size on vcc and GND nets Figure out VCC on Pico Figur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
Pimaroni Trackball
Solenoid
V2 Features: RH Trackball and rotary encoder instead of Pimaroni Move arrow keys into "+" centered around "." on left hand
TRRS jack. (Serial config is default)
Hollow Rotary Encoder for trackball
Rotary Knob

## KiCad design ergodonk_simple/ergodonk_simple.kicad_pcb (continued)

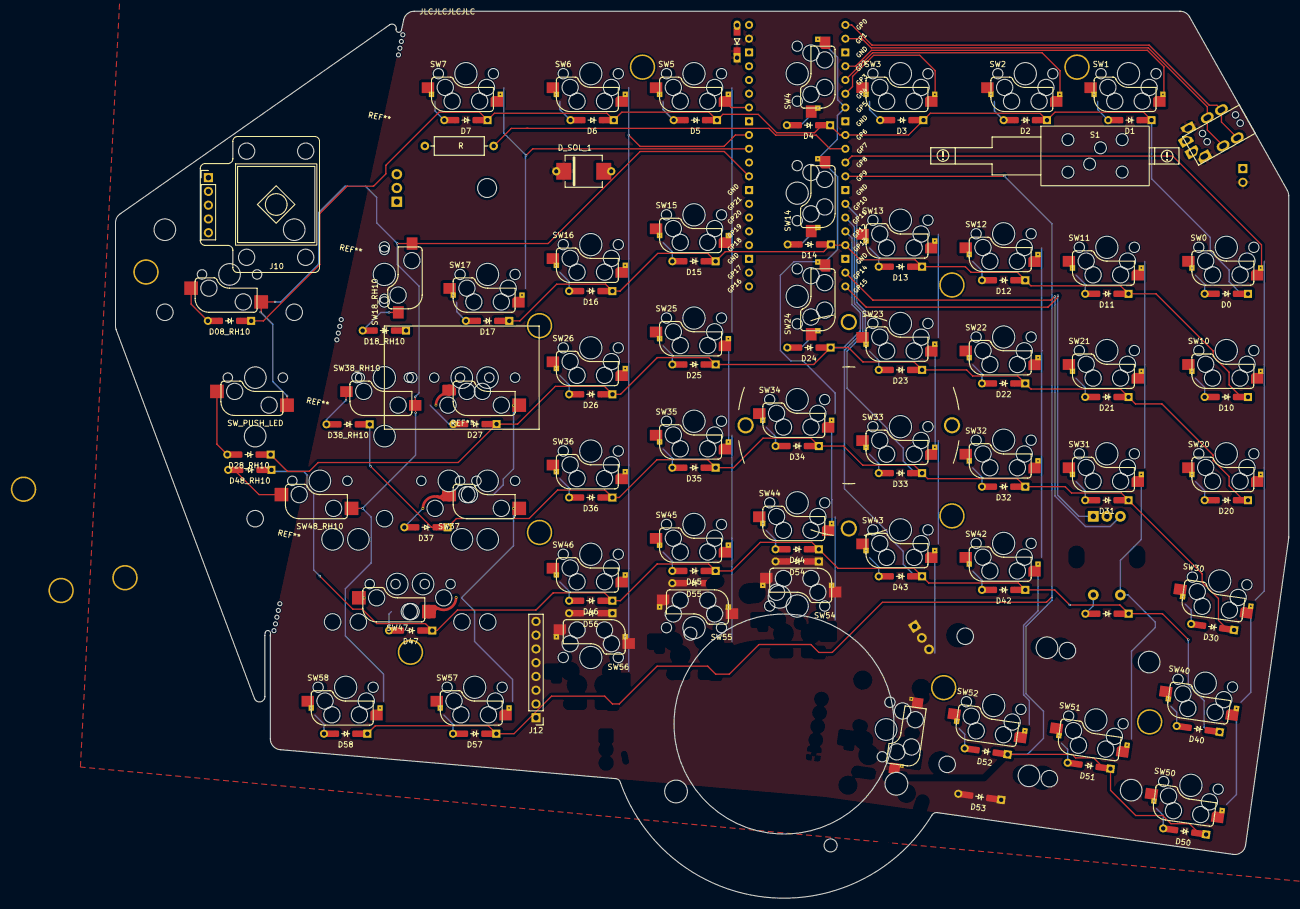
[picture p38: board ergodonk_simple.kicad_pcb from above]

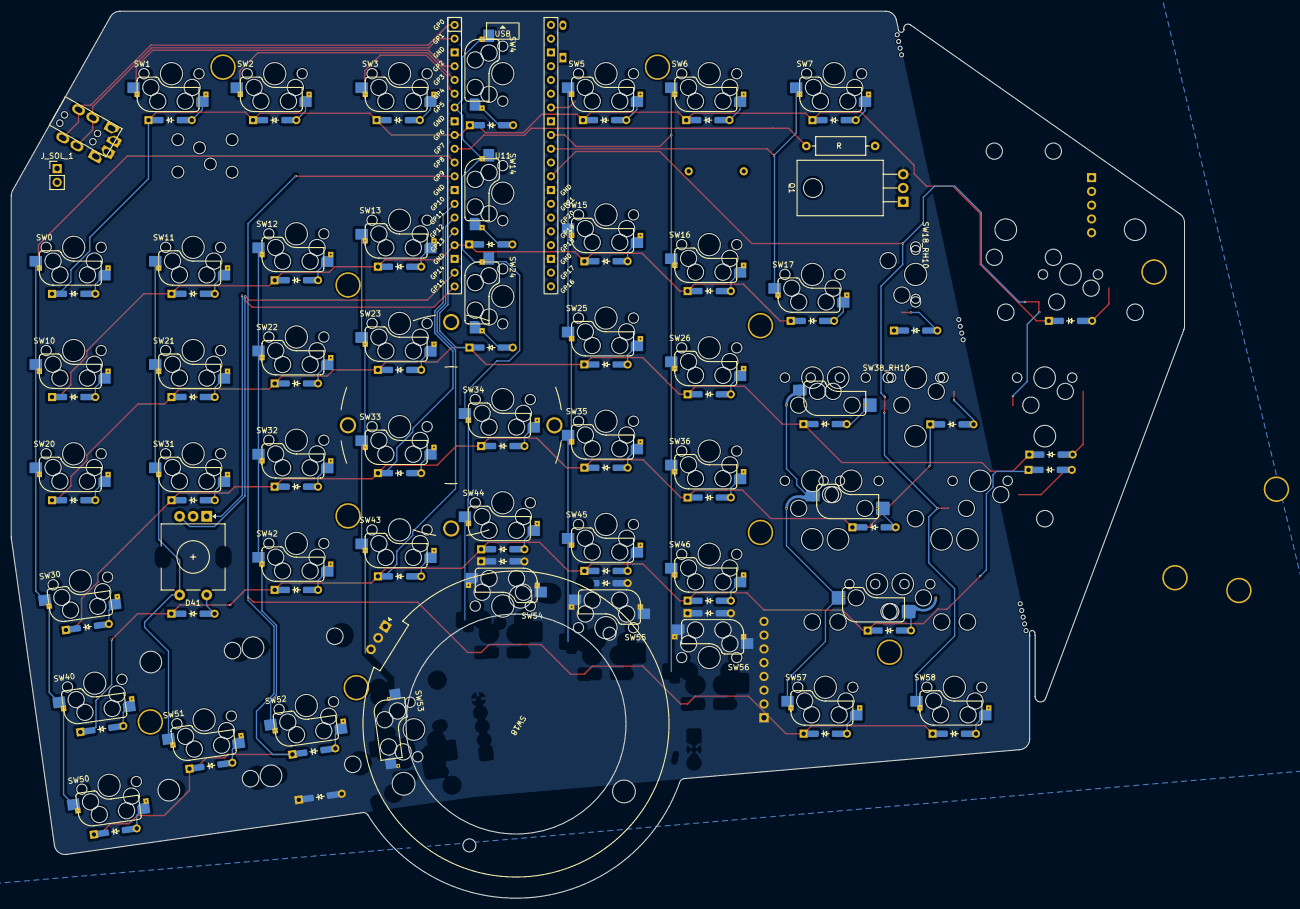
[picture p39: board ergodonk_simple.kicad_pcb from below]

Board: 2 copper layers, 216.6 x 163.7 mm, 132 parts (8 on the bottom side), 85 nets.

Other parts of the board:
D18: D; D3_TH_SMD_v2
J11: 4PIN; MJ-4PP-9_CANTOR_KITCHEN_SINK

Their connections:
GND: J11.1; also elsewhere on the board
unnamed 20: D18.2 (A); also elsewhere on the board
RX: J11.3; also elsewhere on the board
TX: J11.4; also elsewhere on the board
VCC: D18.1 (K), J11.2; also elsewhere on the board

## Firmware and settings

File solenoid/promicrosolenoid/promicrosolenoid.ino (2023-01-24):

int solenoidPin = 9;                    //This is the output pin on the Arduino

void setup() 
{
  pinMode(solenoidPin, OUTPUT);          //Sets that pin as an output
}

void loop() 
{
  digitalWrite(solenoidPin, HIGH);      //Switch Solenoid ON
  delay(1000);                          //Wait 1 Second
  digitalWrite(solenoidPin, LOW);       //Switch Solenoid OFF
  delay(1000);                          //Wait 1 Second
}

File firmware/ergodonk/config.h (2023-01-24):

// Copyright 2022 Ryan Neff (@JellyTitan)
// SPDX-License-Identifier: GPL-2.0-or-later

#pragma once

#include "config_common.h"

// VID and PID moved to .json
// #define VENDOR_ID 0x4A54 // “JT” = JellyTitan.
// #define PRODUCT_ID 0x0001 // Sequential numbering system.
// #define MANUFACTURER    JellyTitan
#define PRODUCT         Ergodonk

/* key matrix size */
// Rows are doubled-up
#define MATRIX_ROWS 14
#define MATRIX_COLS 10
#define MATRIX_COL_PINS   { B8, B7, B10, B5, B4, A0, C15, C14, C13, NO_PIN} 
#define MATRIX_ROW_PINS  { B12, B13, B14, B15, A8, A15, B3 }
// RH has one more col then LH.
#define MATRIX_COL_PINS_RIGHT { C13, C14, C15, A0, B4, B5, B10, B7, B8, B9 }
#define MATRIX_ROW_PINS_RIGHT { B12, B13, B14, B15, A8, A15, B3 }
// #define UNUSED_PINS { A1, A2, A3, A9, A10, A11, A12}

// @todo - what does this do? It was in zv48 . . .
// #define MATRIX_IO_DELAY 5
#define SPLIT_USB_DETECT
#define SPLIT_HAND_PIN B0  // high = left, low = right
// @todo - this is a better way to determine handedness:
// #define SPLIT_HAND_MATRIX_GRID D0, F1

#define SOFT_SERIAL_PIN B6

// If you’re having issues with serial communication, you can change this value, 
// as it controls the communication speed for serial. 
// The default is 1, and the possible values are:
// 0: about 189kbps (Experimental only)
// 1: about 137kbps (default)
// 2: about 75kbps
// 3: about 39kbps
// 4: about 26kbps
// 5: about 20kbps
#define SELECT_SOFT_SERIAL_SPEED 2

// This sets the maximum number of failed communication attempts (one per scan cycle) 
// from the master part before it assumes that no slave part is connected. 
// This makes it possible to use a master part without the slave part connected.
// Set to 0 to disable the disconnection check altogether.
#define SPLIT_MAX_CONNECTION_ERRORS 0

/* Set 0 if debouncing isn't needed  - cribbed from zv48*/
#define DEBOUNCE 5


#define ENCODERS_PAD_A { A13 }
#define ENCODERS_PAD_B { A14 }

#define SOLENOID_PIN B1
#define SOLENOID_ACTIVE true
#define SOLENOID_DEFAULT_DWELL 12 // default is 12.
#define SOLENOID_DWELL_STEP_SIZE 2         //      |The step size to use when `HPT_DWL*` keycodes are sent.
#define SOLENOID_MIN_DWELL 4 // 4 is default
#define SOLENOID_MAX_DWELL 100 // 100 is default

// Prevents thumper on mods like shift/Ctrl/Alt
// #define NO_HAPTIC_MOD

// Bootmagic lite
// LH Hold ESC on boot to enter bootloader
#define BOOTMAGIC_LITE_ROW 0
#define BOOTMAGIC_LITE_COLUMN 1
// RH Hold DEL on boot to enter bootloader 
// @todo this is only needed when using SPLIT_HAND_PIN or EE_HANDS
// https://docs.qmk.fm/#/feature_bootmagic?id=split-keyboards
#define BOOTMAGIC_LITE_ROW_RIGHT 7
#define BOOTMAGIC_LITE_COLUMN_RIGHT 7

/* If you type too fast, it confuses the Mod key combos. This resolves it: */
#define IGNORE_MOD_TAP_INTERRUPT
/* Set tapdance speed */
#define TAPPING_TERM 210

/* Allows for the setting of constant mouse speed levels. */
/* Delay between pressing a movement key and cursor movement */
#define MOUSEKEY_DELAY 10
/* Time between cursor movements in milliseconds */
#define MOUSEKEY_INTERVAL 16
/* Step size */
#define MOUSEKEY_MOVE_DELTA 8
/* Maximum cursor speed at which acceleration stops */
#define MOUSEKEY_MAX_SPEED 2
/* Time until maximum cursor speed is reached */
#define MOUSEKEY_TIME_TO_MAX 40
/* Maximum number of scroll steps per scroll action */
#define MOUSEKEY_WHEEL_MAX_SPEED 42
/* Time until maximum scroll speed is reached */
#define MOUSEKEY_WHEEL_TIME_TO_MAX 15


// #define XXX KC_NO
#define XXX KC_NO
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

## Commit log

2022-11-28 blackpill holder first iteration
    [case.stl]
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2022-12-08 Blackpill holder trrs jack imports
    [FC68128.IGS, FC68128.SLDPRT, FC68128.STEP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]
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2023-01-17 Updated PCB created new footprints based on kbd hybrid TH/SMD diodes Swapped IN4004 for MUR340 in Solenoid Routing and Blackpill placement Added RP2040 symbol/footprint submodule
    [MUR340S.step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]
2023-01-20 LH single side pcb first draft complete sent this version to jlcpcb for prototype production
    [ergodonk_pcb-B_Cu.gbl, ergodonk_pcb-B_Cu.gbr, ergodonk_pcb-B_Mask.gbr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]
2023-01-20 Synchronized updated footprints with schematics
    [ergodonk_pcb.kicad_pcb, ergodonk_pcb.kicad_sch]
2023-01-22 Moved customezed footprints to seperate library and updated schematic association
    [ergodonk_pcb.kicad_sch]
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2023-01-22 Added 2u Screw in stabalizers and rerouted wiring
    [ergodonk_pcb.kicad_pcb, ergodonk_pcb.kicad_sch]
2023-01-24 Wiring cleanup, started adding LEDs
    [ergodonk_pcb.kicad_pcb]
2023-01-24 Updated schematic to V2 wiring - frees up one more pin[B (b3)
    [ergodonk_pcb.kicad_sch]
2023-01-24 Updated wiring on pcb to v2, ran DRC
    [ergodonk_pcb.kicad_pcb, ergodonk_pcb.kicad_sch]
2023-01-27 Revised RH wiring diagram and added 3d component models
    [EC11_Rotary_Encoder_Switched.step, FC68128.IGS, FC68128.SLDPRT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]
2023-01-31 Added KiCad libraries for rp2040 pro micro and Sofle Choc
    [Da-ProMicro.prt, Dp-PCB板.prt, Dp-Type-C16p.prt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]
2023-02-01 Created Cherry MX Doublesided mini-e footprint variant and updated schematic
    [ergodonk_pcb.kicad_pcb, ergodonk_pcb.kicad_sch]
2023-02-01 LED layout before mirroroing
    [ergodonk_pcb.kicad_sch]
2023-02-01 Button & LED reference sync
    [ergodonk_pcb.kicad_pcb, ergodonk_pcb.kicad_sch]
2023-02-01 Alpha key LED schematic wiring
    [ergodonk_pcb.kicad_sch]
2023-02-01 Reveresed nrow/column umbering systme to support double sided
    [ergodonk_pcb.kicad_pcb, ergodonk_pcb.kicad_sch]
2023-02-02 Right hand added Built new footprints for RH/LH combo keys Added jumpers for optional LEDs"
    [ergodonk_pcb.dsn, ergodonk_pcb.kicad_pcb, ergodonk_pcb.kicad_sch]
2023-02-02 Added edgecuts with breakaway right hand
    [ergodonk_pcb.kicad_pcb]
2023-02-04 Added speaker and cleaned up diode placement
    [AST1109MLTRQ_MAL.step, PER561-P115-N0015.stp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]
2023-02-04 Resolved LED jumper sequence and comments
    [ergodonk_pcb.kicad_pcb, ergodonk_pcb.kicad_sch]
2023-02-13 First draft of Bourns hollow encoder footprint (sent out for prototype)
    [ergodonk_pcb.kicad_pcb, ergodonk_pcb.kicad_sch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]
2023-02-19 Removed hand indication pin pin and updated footprints
    [ergodonk_pcb.kicad_sch]
2023-02-26 Increased default net width and removed LED initial jumper
    [ergodonk_pcb.kicad_sch]
2023-02-26 Switch footprint refactor Hotswop outline replaced and rounded Hotswap pad numbering aligned per side Hotswap pad traces and vias added miniE led footprint with doublesided vias added Schematics upda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
    [ergodonk_pcb.kicad_sch]
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2023-02-27 Rewired to 2040 begun Rewired rows and columns Added net names for rows and columns. Removed Key 00 to make room for PI Added OLED Added SDA/SDL breakout for optional Pimoroni
    [ergodonk_pcb.kicad_sch]
2023-03-01 Updated PCB from schematicatic, diode cleanup
    [ergodonk_pcb.kicad_sch]
2023-03-01 Simplified LED config to mirror Keebio Sync Rev3
    [ergodonk_pcb.kicad_sch]
2023-03-01 Removed blackpill from schematic and pcb Updated pico placement Updated outline source for Inkscape regeneration
    [ergodonk_pcb.kicad_sch]
2023-03-01 Added pimaroni rough symbol
    [ergodonk_pcb.kicad_sch]
2023-03-07 TRRS cleanup pimironi revision outline rework
    [ergodonk_pcb.kicad_sch]
2023-03-07 Fixed MUR340 Hybrid footprint Regenerated .dsn for autorouting
    [ergodonk_pcb.kicad_pcb, ergodonk_pcb.kicad_sch, ergodonk_pcb2.dsn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]
2023-03-07 Added zones Wired VCC to VDD for LED Regenerated dsn for autorouting
    [ergodonk_pcb.kicad_sch, ergodonk_pcb4.dsn]
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2023-03-09 Regenerated .dsn with ground and VCC zones
    [ergodonk_pcb.kicad_sch, ergodonk_pcb4.dsn]
2023-03-10 Revised solenoid footrpints and layout for easier soldering and better fit
    [ergodonk_pcb.kicad_sch]
2023-03-12 Schematic cleanup for review/assistance
    [ergodonk_pcb.kicad_sch]
2023-03-13 Rewired to VBus for 5V and updated dsn
    [ergodonk_pcb.kicad_sch, ergodonk_pcb5.dsn]
2023-03-14 Mounting hole realingmngment for top plate
    [ergodonk_pcb.kicad_sch]
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2023-04-04 General commit before switching machines
    [cherry mx placeholder diagonal v11.step]
2023-04-06 Integrated led footprint from sofle choc_mx Updated schematic from PCB Moved diodes to RH of switches started wiring
    [ergodonk_pcb.kicad_sch]
2023-04-12 Routing first pass updated keyswitch footprints
    [ergodonk_pcb.kicad_sch]
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2023-04-27 Wiring cleanup for Elite-C variant
    [ergodonk_pcb.kicad_sch]
2023-05-07 Flipped diodes added tenting puck started rewire with new diode orientation
    [ergodonk_pcb.kicad_sch]
2023-05-11 Added seperate kicad project for pi pico non double-sided
    [ergodonk_pico.kicad_sch]
2023-06-06 Ergodonk pico schematic update
    [ergodonk_pico.kicad_sch]
2023-06-06 Added elite-c variant as subfolder
    [MUR340S.step, Pico.skp, Test.kicad_pcb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]
2023-06-06 Moved F row to accomidate mid board Pico mcu
    [ergodonk_pcb.kicad_sch]
2023-06-07 Updated pico RH schematics
    [ergodonk_pico.kicad_sch]
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2023-06-08 Pico schematic switch nubmering changed to row/col intersection
    [ergodonk_pico.kicad_sch]
2023-06-09 Pico leds re-added to schemematic PCB rough key layout
    [ergodonk_pico.kicad_sch]
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2023-06-11 Thumb rotation diode placement added tenting puck symbols and footprint
    [ergodonk_pico.kicad_pcb, ergodonk_pico.kicad_sch]
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2023-07-21 pcb simple with encoder checkpoint before outline mod
    [MUR340S.step, Pico.skp, Test.kicad_pcb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]
2023-07-23 Flipped rotary encoder to backside
    [ergodonk_simple.kicad_pcb, ergodonk_simple.kicad_sch]
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2023-07-28 Moved trace away from ec11 plated support slot to prevent short
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2023-11-20 ergodonk simple zero checkpoint before choc MX switch swap
    [ergodonk_simple_zero.kicad_sch]
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

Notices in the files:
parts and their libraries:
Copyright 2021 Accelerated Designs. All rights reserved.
